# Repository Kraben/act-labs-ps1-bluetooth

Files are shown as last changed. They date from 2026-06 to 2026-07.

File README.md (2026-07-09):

# ACT Labs REX PS1 Replacement PCB

> Placa de repuesto open-source para el **ACT Labs REX Arcade Stick de PS1**.

```text
Status: Hardware V2 / KiCad actualizado
Firmware publico: PS1 Digital v1.1 OK
Firmware de apoyo: Hybrid AUTO PS1 / PS2 / BLE
BLE: operativo
Fabricacion: Gerbers pendientes de actualizar
Edicion: KiCad completo actualizado
```

## Project Dashboard

| Area | Estado | Alcance |
|---|---|---|
| Hardware | V2 / KiCad actualizado | Publico |
| Firmware PS1 | PS1 Digital v1.1 OK | Publico |
| Firmware binary | [`ActLabs_PS1_Digital_v1.1_OK.bin`](firmware/releases/PS1_Digital/v1.1/ActLabs_PS1_Digital_v1.1_OK.bin) | Publico |
| BLE HID | Operativo | Publico |
| AutoFire | Documentado | Publico |
| KiCad editable | Actualizado en `hardware/kicad/ACT_Labs_REX/` | Publico |
| Gerbers fabricacion | Pendientes de regenerar desde la revision KiCad actual | Publico |
| PS2 / DualShock | Listo en firmware Hybrid AUTO | Build de apoyo / donativos |
| PS1/PS2/BLE Hybrid | Listo en firmware Hybrid AUTO | Build de apoyo / donativos |

## Quick Links

| Recurso | Link |
|---|---|
| Sitio web | https://kraben.github.io/act-labs-ps1-bluetooth/ |
| Descargar firmware PS1 v1.1 | [`ActLabs_PS1_Digital_v1.1_OK.bin`](firmware/releases/PS1_Digital/v1.1/ActLabs_PS1_Digital_v1.1_OK.bin) |
| Firmware notes | [`docs/firmware.md`](docs/firmware.md) |
| Firmware Hybrid AUTO | [`docs/supporter-build.md`](docs/supporter-build.md) |
| Interfaz PS1 | [`docs/interfaces/ps1.md`](docs/interfaces/ps1.md) |
| Mapeo GPIO | [`docs/mapeo-gpio.md`](docs/mapeo-gpio.md) |
| Conectores | [`docs/conectores.md`](docs/conectores.md) |
| AutoFire | [`docs/autofire.md`](docs/autofire.md) |
| BOM | [`docs/bom.md`](docs/bom.md) |
| Fabricacion | [`docs/fabricacion.md`](docs/fabricacion.md) |
| KiCad editable | [`hardware/kicad/ACT_Labs_REX/`](hardware/kicad/ACT_Labs_REX/) |
| Gerbers | [`hardware/fabrication/gerbers/ACT_Labs_REX/`](hardware/fabrication/gerbers/ACT_Labs_REX/) |

## Resumen

El objetivo de este repositorio es conservar y documentar una alternativa de reemplazo para el control ACT Labs REX, ya que la pieza original ya no se fabrica ni se consigue facilmente.

El sistema usa un ESP32 DevKit V1 como controlador principal para reemplazar la electronica del ACT Labs REX Arcade Stick de PS1.

## Firmware publico PS1

La version publica actual del firmware es:

```text
ActLabs_PS1_Digital_v1.1_OK.bin
```

| Campo | Valor |
|---|---|
| Version | PS1 Digital v1.1 |
| Estado | OK |
| Target | ACT Labs REX PS1 Replacement PCB |
| Hardware | V2 / KiCad actualizado |
| Ruta | [`firmware/releases/PS1_Digital/v1.1/`](firmware/releases/PS1_Digital/v1.1/) |
| Archivo | [`ActLabs_PS1_Digital_v1.1_OK.bin`](firmware/releases/PS1_Digital/v1.1/ActLabs_PS1_Digital_v1.1_OK.bin) |
| SHA256 | `0a8994050381326bf345bf8123c105abefadabf30187247be9129a8c7f34b15c` |
| MD5 | `f61375d0dea1b9e42a6903105f5fba79` |

## Firmware Hybrid AUTO de apoyo

El firmware Hybrid AUTO es una build avanzada para ESP32 pensada como opcion de apoyo/donativos al proyecto.

| Funcion | Estado |
|---|---|
| PS1 cableado | Listo |
| PS2 / DualShock | Listo |
| Bluetooth BLE HID | Listo |
| Deteccion automatica PS1 / PS2 / BLE | Listo |

La documentacion publica se mantiene en [`docs/supporter-build.md`](docs/supporter-build.md). El codigo fuente completo del firmware Hybrid AUTO no se publica en este repositorio publico.

## Modos documentados

| Modo | Descripcion | Estado |
|---|---|---|
| PS1 cableado | ESP32 emula un control digital PS1 usando DATA, CMD, ATT, CLK y ACK. | Publico |
| Bluetooth HID | ESP32 funciona como gamepad BLE cuando se usa con bateria. | Publico |
| AutoFire | Placa secundaria con switches SPDT para activar turbo por boton. | Publico |
| Firmware Hybrid AUTO | PS1 / PS2 / BLE con deteccion automatica. | Build de apoyo / donativos |

## Estructura limpia

```text
.
├── docs/
│   ├── firmware.md
│   ├── supporter-build.md
│   ├── mapeo-gpio.md
│   ├── conectores.md
│   ├── autofire.md
│   └── interfaces/ps1.md
├── hardware/
│   ├── fabrication/
│   │   └── gerbers/
│   │       └── ACT_Labs_REX/
│   ├── kicad/
│   │   └── ACT_Labs_REX/
│   ├── pdf/
│   └── images/
├── data/
└── firmware/
    ├── ACT_Labs_Controller/
    └── releases/
        └── PS1_Digital/
            └── v1.1/
```

## Para fabricar vs para editar

| Uso | Carpeta | Contenido |
|---|---|---|
| Editar proyecto | [`hardware/kicad/ACT_Labs_REX/`](hardware/kicad/ACT_Labs_REX/) | Proyecto KiCad completo actualizado |
| Fabricar PCB | [`hardware/fabrication/gerbers/ACT_Labs_REX/`](hardware/fabrication/gerbers/ACT_Labs_REX/) | Gerbers pendientes de regenerar desde la revision KiCad actual |
| Firmware publico | [`firmware/releases/PS1_Digital/v1.1/`](firmware/releases/PS1_Digital/v1.1/) | Binario PS1 Digital v1.1 |
| Revisar PDFs | [`hardware/pdf/`](hardware/pdf/) | Esquematicos y PCB en PDF |
| Revisar datos | [`data/`](data/) | Mapeos, CSV y hojas de apoyo |

## Archivos de fabricacion actuales

> Nota: los Gerbers existentes pueden no corresponder todavia a la revision KiCad mas reciente. Regenerar y validar antes de fabricar.

| Archivo | Proposito |
|---|---|
| `ACT_Labs_REX-F_Cu.gbr` | Cobre superior |
| `ACT_Labs_REX-B_Cu.gbr` | Cobre inferior |
| `ACT_Labs_REX-F_Mask.gbr` | Mascara superior |
| `ACT_Labs_REX-B_Mask.gbr` | Mascara inferior |
| `ACT_Labs_REX-F_Silkscreen.gbr` | Serigrafia superior |
| `ACT_Labs_REX-B_Silkscreen.gbr` | Serigrafia inferior |
| `ACT_Labs_REX-Edge_Cuts.gbr` | Contorno de PCB |
| `ACT_Labs_REX-PTH.drl` | Taladros metalizados |
| `ACT_Labs_REX-NPTH.drl` | Taladros no metalizados |
| `ACT_Labs_REX-job.gbrjob` | Job file de fabricacion |

## Referencias de hardware

| Archivo | Descripcion |
|---|---|
| [`hardware/pdf/ACT_Labs_REX.pdf`](hardware/pdf/ACT_Labs_REX.pdf) | Esquematico principal |
| [`hardware/pdf/ArcLabsPCB.pdf`](hardware/pdf/ArcLabsPCB.pdf) | PCB principal |
| [`hardware/pdf/AutoFire.pdf`](hardware/pdf/AutoFire.pdf) | Esquematico AutoFire |
| [`hardware/pdf/AutoFirePCB.pdf`](hardware/pdf/AutoFirePCB.pdf) | PCB AutoFire |
| [`hardware/fabrication/`](hardware/fabrication/) | BOM/POS de fabricacion |

## Pines principales V2

| Signal | GPIO |
|---|---:|
| DATA | 19 |
| CMD | 23 |
| ATT | 5 |
| CLK | 18 |
| ACK | 4 |
| START | 2 |
| SELECT | 16 |
| AF_MODE | 15 |

## Apoyo / donativos

GitHub Pages puede funcionar como landing page del proyecto y enlazar a una plataforma externa para apoyo/donativos.

Opciones recomendadas:

| Opcion | Uso recomendado |
|---|---|
| GitHub Pages + PayPal/Mercado Pago | Catalogo simple y contacto directo |
| GitHub Pages + Gumroad/Payhip/Ko-fi | Entrega de builds de apoyo, firmware o archivos digitales |
| GitHub Pages + Stripe Payment Links | Botones de pago profesionales sin backend propio |
| GitHub Sponsors | Apoyo/donaciones recurrentes |

El repositorio publico mantiene hardware, documentacion y firmware PS1 disponible. La build Hybrid AUTO se maneja como opcion avanzada de apoyo para sostener el desarrollo.

## Proximos pasos

- [ ] Regenerar Gerbers desde la revision KiCad actual.
- [ ] Validar Gerbers nuevos contra visualizador antes de mandar a fabricar.
- [ ] Validar continuidad START/SELECT contra GND en PCB actualizada.
- [ ] Validar continuidad entre PCB principal, placa AutoFire y conectores JP.
- [ ] Revisar la ruta de alimentacion `BATT_FROM_TP`, TP4056, LD1117-3.3 y diodos SS14.
- [ ] Validar el firmware PS1 actualizado contra hardware fisico.
- [ ] Confirmar pull-ups reales contra la PCB antes de fabricar.
- [ ] Preparar binario, checksums y guia de flasheo para la build Hybrid AUTO de apoyo.

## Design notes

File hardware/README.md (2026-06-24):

# Hardware

Esta carpeta contiene referencias de hardware, PDFs, imágenes, exportaciones de fabricación e inventario de fuentes KiCad del proyecto ACT Labs PS1 Bluetooth / AutoFire.

## PDFs

- `pdf/ACT_Labs_REX.pdf`: esquemático principal de conversión de tablero PS1.
- `pdf/ArcLabsPCB.pdf`: vista de PCB principal.
- `pdf/AutoFire.pdf`: esquemático de la placa AutoFire.
- `pdf/AutoFirePCB.pdf`: vista de PCB AutoFire.

## Imágenes

- `images/Led-Switch.png`: detalle de LED / switch de encendido.
- `images/Partcial_SCHM.png`: captura parcial del esquemático principal.
- `images/SW_part.png`: captura de la placa de switches AutoFire.

## Fabricación

Archivos de resumen derivados de las exportaciones KiCad recibidas:

- `fabrication/ACT_Labs_REX_BOM_summary.csv`: BOM resumido de placa principal.
- `fabrication/ACT_Labs_REX_POS_summary.csv`: posiciones resumidas de placa principal.
- `fabrication/autofire_bom_summary.txt`: BOM resumido de placa AutoFire.
- `fabrication/autofire_pos_summary.txt`: posiciones resumidas de placa AutoFire.

Resumen de exportaciones recibidas:

| Placa | BOM | POS | Componentes |
|---|---:|---:|---:|
| ACT_Labs_REX | 35 líneas | 40 líneas | 27 top / 13 bottom |
| AutoFire | 13 líneas | 13 líneas | 13 top |

## Fuentes KiCad

El inventario de fuentes KiCad recibidas y sus hashes está en `kicad/SOURCES.md`.

## Validaciones recomendadas

- Verificar continuidad de GND entre placas.
- Confirmar orientación de D1/D3 Schottky.
- Confirmar que `BATT_FROM_TP` entra a la ruta de alimentación correcta y no directamente a `3V3`.
- Confirmar pull-ups de DATA/ACK a 4.7 kΩ según BOM V2.
- Antes de fabricar, regenerar BOM/POS desde la misma revisión de KiCad que se use para Gerbers.

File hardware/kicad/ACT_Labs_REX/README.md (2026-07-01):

# ACT Labs REX KiCad Sources

Fuentes editables de KiCad para **ACT Labs REX PCB V2.2**.

## Uso

Esta carpeta es para editar el proyecto en KiCad.

Para fabricar usar los Gerbers exportados en:

```text
hardware/fabrication/gerbers/ACT_Labs_REX/
```

## Archivos principales

| Archivo | Proposito |
|---|---|
| ACT_Labs_REX.kicad_pro | Proyecto KiCad |
| ACT_Labs_REX.kicad_sch | Esquematico principal |
| ACT_Labs_REX.kicad_pcb | PCB principal |
| Placa_2.kicad_sch | Esquematico de placa secundaria / AutoFire |

## Reglas

- Mantener aqui solo fuentes editables de KiCad.
- No mezclar Gerbers ni salidas de fabricacion en esta carpeta.
- No subir backups, autosaves ni archivos temporales.
- Exportar salidas de fabricacion hacia `hardware/fabrication/gerbers/ACT_Labs_REX/`.

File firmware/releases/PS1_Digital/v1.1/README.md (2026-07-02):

# ACT Labs PS1 Digital Firmware v1.1

Firmware publico para la placa **ACT Labs REX PS1 Replacement PCB**.

## Archivo

```text
ActLabs_PS1_Digital_v1.1_OK.bin
```

## Estado

| Campo | Valor |
|---|---|
| Version | PS1 Digital v1.1 |
| Estado | OK |
| Target | ACT Labs REX PS1 Replacement PCB |
| Hardware | V2 / PCB V2.2 |

## Checksum

```text
SHA256: 0a8994050381326bf345bf8123c105abefadabf30187247be9129a8c7f34b15c
MD5: f61375d0dea1b9e42a6903105f5fba79
```

## Politica de publicacion

Este release contiene el firmware publico PS1 Digital.

El protocolo PS2 / DualShock y el firmware hibrido PS1/PS2/BLE permanecen reservados para distribucion privada/paywall.

## Antes de flashear

- Confirmar que el hardware sea ACT Labs REX V2 / PCB V2.2.
- Confirmar checksum del archivo descargado.
- Validar alimentacion y cableado antes de probar en consola.

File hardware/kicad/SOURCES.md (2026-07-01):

# Fuentes KiCad V2

Inventario de archivos recibidos para trazabilidad de la revision V2 / PCB V2.2.

## Estructura actual

```text
hardware/kicad/
├── ACT_Labs_REX/
│   ├── ACT_Labs_REX.kicad_pro
│   ├── ACT_Labs_REX.kicad_sch
│   ├── ACT_Labs_REX.kicad_pcb
│   └── Placa_2.kicad_sch
└── SOURCES.md
```

## Fabricacion

Los Gerbers actuales estan separados de las fuentes editables:

```text
hardware/fabrication/gerbers/ACT_Labs_REX/
├── ACT_Labs_REX-F_Cu.gbr
├── ACT_Labs_REX-B_Cu.gbr
├── ACT_Labs_REX-F_Mask.gbr
├── ACT_Labs_REX-B_Mask.gbr
├── ACT_Labs_REX-F_Paste.gbr
├── ACT_Labs_REX-B_Paste.gbr
├── ACT_Labs_REX-F_Silkscreen.gbr
├── ACT_Labs_REX-B_Silkscreen.gbr
├── ACT_Labs_REX-Edge_Cuts.gbr
├── ACT_Labs_REX-PTH.drl
├── ACT_Labs_REX-NPTH.drl
└── ACT_Labs_REX-job.gbrjob
```

## Regla de limpieza

- Para editar: usar `hardware/kicad/ACT_Labs_REX/`.
- Para fabricar: usar `hardware/fabrication/gerbers/ACT_Labs_REX/`.
- No mezclar archivos Gerber dentro de KiCad.
- No mezclar fuentes KiCad dentro de fabricacion.
- No subir backups, autosaves o temporales de KiCad.

## Nota

Los CSV de resumen de BOM/POS de esta revision permanecen en `hardware/fabrication/`.

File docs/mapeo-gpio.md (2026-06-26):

# Mapeo GPIO ESP32 Rev 1.4 / V2

Mapa funcional actualizado desde `ACT_Labs_Mapeo_Consolidado(2).xlsx` y `gpio_mapping.csv`.

Referencia externa usada como apoyo: Random Nerd Tutorials, `ESP32 Pinout Reference: Which GPIO pins should you use?`, agregada para validar restricciones generales de GPIO del ESP32.

## Botones frontales

| # | Señal / función | GPIO ESP32 | JP / conector | Pin conector | Tipo | Pull-up | Notas |
|---:|---|---|---|---|---|---|---|
| 1 | Triángulo | GPIO14 | JP1 / JP2 | 6 / 1 | INPUT | PULLUP interno | AF_TRIANGULO - SW7 Placa_2 |
| 2 | Círculo | GPIO26 | JP1 / JP2 | 7 / 2 | INPUT | PULLUP interno | AF_CIRCULO - SW3 Placa_2 |
| 3 | Cuadrado | GPIO12 | JP1 / JP2 | 4 / 6 | INPUT | PULLUP interno | AF_CUADRADO - SW6 Placa_2 |
| 4 | Cruz | GPIO25 | JP1 / JP2 | 8 / 4 | INPUT | PULLUP interno | AF_CRUZ - SW2 Placa_2 |

## Botones laterales

| # | Señal / función | GPIO ESP32 | JP / conector | Pin conector | Tipo | Pull-up | Notas |
|---:|---|---|---|---|---|---|---|
| 6 | L1 | GPIO27 | JP1 / JP4 | 7 / 5 | INPUT | PULLUP interno | AF_L1 - SW1 Placa_2 |
| 7 | L2 | GPIO32 | JP1 / JP4 | 10 / 4 | INPUT | PULLUP interno | AF_L2 - SW4 Placa_2 |
| 8 | R1 | GPIO33 | JP1 / JP4 | 8 / 1 | INPUT | PULLUP interno | AF_R1 - SW5 Placa_2 |
| 9 | R2 | GPIO13 | JP1 / JP4 | 3 / 7 | INPUT | PULLUP interno | AF_R2 - SW8 Placa_2 |

## D-Pad

| # | Señal / función | GPIO ESP32 | JP | Pin | Tipo | Pull-up | Notas |
|---:|---|---|---|---|---|---|---|
| 11 | Arriba | GPIO36 | JP3 | 8 | INPUT ONLY | 10k externo R1 | Sin pull-up interno |
| 12 | Abajo | GPIO34 | JP3 | 2 | INPUT ONLY | 10k externo R4 | Sin pull-up interno |
| 13 | Izquierda | GPIO35 | JP3 | 4 | INPUT ONLY | 10k externo R3 | Sin pull-up interno |
| 14 | Derecha | GPIO39 | JP3 | 6 | INPUT ONLY | 10k externo R5 | Sin pull-up interno |

## START / SELECT

| # | Señal | GPIO ESP32 | Conector | Pin conector | Tipo | Pull-up | Notas |
|---:|---|---|---|---|---|---|---|
| 16 | START | GPIO2 | JP1 / START1 | 12 / - | INPUT | PULLUP interno + R6 15k | SW_Push_Dual; GPIO2 es pin de arranque y puede afectar boot si se fuerza en nivel incorrecto |
| 17 | SELECT | GPIO16 | JP1 / SELECT1 | 12 / - | INPUT | PULLUP interno + R7 15k | SW_Push_Dual |

## Interfaz PS1 SPI

| # | Señal | GPIO ESP32 | Conector | Pin | Tipo | Pull-up | Notas |
|---:|---|---|---|---|---|---|---|
| 19 | PS1_DATA / MISO | GPIO19 | PS1_Conn | 1 | OUTPUT | R1 1k a 3V3 | Mando a consola; coincide con MISO VSPI por defecto |
| 20 | PS1_CMD / MOSI | GPIO23 | PS1_Conn | 2 | INPUT | - | Consola a mando; coincide con MOSI VSPI por defecto |
| 21 | PS1_ATT / CS | GPIO5 | PS1_Conn | 6 | INPUT | - | LOW = consola iniciando comunicación; GPIO5 es strapping pin |
| 22 | PS1_CLK | GPIO18 | PS1_Conn | 7 | INPUT | - | Reloj aprox 250kHz; coincide con CLK VSPI por defecto |
| 23 | PS1_ACK | GPIO4 | PS1_Conn | 8 | OUTPUT | - | Pulso LOW aprox 2us |

## AutoFire / alimentación

| # | Señal | GPIO ESP32 | JP | Pin | Tipo | Pull-up | Notas |
|---:|---|---|---|---|---|---|---|
| 25 | AF_MODE | GPIO15 | JP1 | 2 | INPUT | PULLUP interno | SW9 Placa_2; GPIO15 es strapping pin y puede emitir señal durante boot |
| 26 | BATT_FROM_TP | VIN | JP1 | 12 | PWR | - | SW10 Placa_2 - Encendido modo BT |
| 27 | VCC_3V3 | 3V3 | JP1 | 1 | PWR | - | Alimenta Placa_2 |
| 28 | GND | GND | JP1 | 13 | GND | - | Referencia común |

## Constantes sugeridas para firmware

```cpp
static constexpr uint8_t PIN_PS1_DATA = 19;
static constexpr uint8_t PIN_PS1_CMD  = 23;
static constexpr uint8_t PIN_PS1_ATT  = 5;
static constexpr uint8_t PIN_PS1_CLK  = 18;
static constexpr uint8_t PIN_PS1_ACK  = 4;

static constexpr uint8_t PIN_START   = 2;
static constexpr uint8_t PIN_SELECT  = 16;
static constexpr uint8_t PIN_AF_MODE = 15;
```

## Notas ESP32 pinout

- GPIO34, GPIO35, GPIO36 y GPIO39 son solo entrada y no tienen pull-up/pull-down internos; por eso el D-Pad necesita resistencias externas.
- GPIO6 a GPIO11 no deben usarse porque normalmente estan conectados a la memoria SPI flash interna del ESP32.
- GPIO2, GPIO5, GPIO12 y GPIO15 son pines sensibles durante el arranque; evitar que botones o switches los fuercen a niveles no deseados al encender.
- El mapeo PS1 usa GPIO23, GPIO19, GPIO18 y GPIO5, que coinciden con la asignacion VSPI habitual del ESP32: MOSI=23, MISO=19, CLK=18 y CS=5.

## Referencias

- Random Nerd Tutorials - ESP32 Pinout Reference: https://randomnerdtutorials.com/esp32-pinout-reference-gpios/

## Nota de revisión

El mapeo consolidado Rev 1.4 corrige `START` a GPIO2 y `SELECT` a GPIO16. Esto reemplaza la tabla anterior que los listaba como GPIO21/GPIO22.

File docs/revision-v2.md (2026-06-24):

# Revision V2 / PCB V2.2

## Estado recibido

- Proyecto principal: `ACT_Labs_REX`
- Titulo PCB principal: `CONVERSION PLACA ARCADE PS1-BLUETOOTH`
- Revision PCB principal: `2.2`
- KiCad: 10.0
- BLE: operativo
- PS1: en depuracion de `ACK` / `DATA`

## Cambios incorporados a documentacion

| Area | Ajuste |
|---|---|
| Arquitectura | Se documenta ESP32 DevKit V1, TP4056 externo, bateria PS Vita 3.7 V, LD1117-3.3 y Schottky |
| BOM | Se actualiza desde CSV KiCad V2 |
| Conectores | Se agrega TP4056, bateria PS Vita, J1-J6, JP1 y AutoFire |
| Firmware | Se documentan pines Rev 1.4 / V2 y resumen de protocolo PS1 |
| Mapeo GPIO | Se sincroniza con ACT_Labs_Mapeo_Consolidado(2).xlsx y gpio_mapping.csv |
| Fabricacion | Se agregan BOM/POS de placa principal y AutoFire |

## Valores importantes Rev 1.4 / V2

| Senal / componente | Valor / GPIO |
|---|---|
| DATA | GPIO19 |
| CMD | GPIO23 |
| ATT | GPIO5 |
| CLK | GPIO18 |
| ACK | GPIO4 |
| START | GPIO2 |
| SELECT | GPIO16 |
| AF_MODE | GPIO15 |
| Regulador | LD1117S33TR_SOT223 |
| Schottky | SS14 / 1N5817 |

## Archivos revisados en esta actualizacion

| Archivo | Uso |
|---|---|
| `ACT_Labs_Mapeo_Consolidado(2).xlsx` | Mapeo consolidado Rev 1.4 |
| `gpio_mapping.csv` | Fuente tabular del mapeo GPIO |
| `jp1_conector_puente.csv` | Fuente de verdad para pines JP1 |
| `placa_2_autofire.csv` | Tabla funcional de switches AutoFire |
| `firmware_resumen.md` | Resumen de modo, turbo y protocolo PS1 |
| `ACT_Labs_REX_BOM(1).csv` | BOM placa principal |
| `ACT_Labs_REX_POS(1).csv` | POS placa principal |
| `AutoFire_BOM(1).csv` | BOM AutoFire |
| `AutoFire_POS(1).csv` | POS AutoFire |

## Correcciones aplicadas

1. `START` queda en GPIO2.
2. `SELECT` queda en GPIO16.
3. El README y la documentacion de firmware fueron corregidos para reemplazar GPIO21/GPIO22.
4. La tabla de conectores usa `jp1_conector_puente.csv` como fuente de verdad para JP1.
5. Se documenta una inconsistencia detectada en `placa_2_autofire.csv`: algunos pines JP1 no coinciden con la tabla JP1. En conectores se normaliza usando JP1.

## Pendientes tecnicos

1. Subir fuentes KiCad completas si se requiere tener el proyecto 100% editable dentro del repositorio.
2. Generar Gerbers oficiales desde KiCad 10.
3. Validar footprints de switches SPDT antes de fabricar.
4. Medir timing PS1 con analizador logico.
5. Confirmar si el termistor de bateria PS Vita se deja aislado o se integra a una proteccion futura.

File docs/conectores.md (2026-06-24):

# Conectores V2

## TP4056

| Punto | Conexion |
|---|---|
| OUT+ | BATT_FROM_TP |
| OUT- | GND |
| BATT+ | Positivo de bateria PS Vita |
| BATT- | Negativo de bateria PS Vita |

## Bateria PS Vita

| Cable | Senal | Nota |
|---|---|---|
| Rojo | BAT+ | Positivo bateria |
| Negro | BAT- | Negativo bateria |
| Blanco | Termistor | Sin uso en esta revision |

## Conector PS1 J1

| Pin | Senal |
|---:|---|
| 1 | DATA |
| 2 | CMD |
| 3 | VIB_NC |
| 4 | GND |
| 5 | VCC_3V3 |
| 6 | ATT |
| 7 | CLK |
| 8 | NC |
| 9 | ACK |

## JP1 - Conector puente de 13 pines

| Pin JP1 | Senal | Desde | Hacia | GPIO ESP32 | Descripcion |
|---:|---|---|---|---|---|
| 1 | VCC_3V3 | Placa Principal | Placa_2 | 3V3 | Alimentacion 3.3V hacia Placa_2 |
| 2 | AF_MODE | Placa_2 SW9 | ESP32 | GPIO15 | Modo turbo global |
| 3 | AF_R2 | Placa_2 SW8 | ESP32 | GPIO13 | Turbo R2 |
| 4 | AF_CUADRADO | Placa_2 SW6 | ESP32 | GPIO12 | Turbo Cuadrado |
| 5 | NC | - | - | NC | No conectado |
| 6 | AF_TRIANGULO | Placa_2 SW7 | ESP32 | GPIO14 | Turbo Triangulo |
| 7 | AF_L1 | Placa_2 SW1 | ESP32 | GPIO27 | Turbo L1 |
| 8 | AF_R1 | Placa_2 SW5 | ESP32 | GPIO33 | Turbo R1 |
| 9 | AF_CRUZ | Placa_2 SW2 | ESP32 | GPIO25 | Turbo Cruz |
| 10 | AF_CIRCULO | Placa_2 SW3 | ESP32 | GPIO26 | Turbo Circulo |
| 11 | AF_L2 | Placa_2 SW4 | ESP32 | GPIO32 | Turbo L2 |
| 12 | BATT_FROM_TP | Placa_2 SW10 | ESP32 VIN + D1 | VIN | Encendido modo BT - pasa por D1 SS14 |
| 13 | GND | Placa Principal | Placa_2 | GND | Referencia comun |

## Conectores internos de placa principal

| Ref | Nombre | Pines | Funcion |
|---|---|---:|---|
| J2 | JP1 Autofire | 13 | Puente hacia placa AutoFire / senales de turbo |
| J3 | JP3 Palanca Direccional | 8 | D-Pad / palanca direccional |
| J4 | JP4 Botones Frontales | 8 | Triangulo, circulo, cruz, cuadrado y GND |
| J5 | JP5 Botones laterales | 8 | L1, L2, R1, R2 y GND |
| J6 | JP6 Autofire | 13 | Segundo conector de AutoFire segun PCB V2 |

## Placa AutoFire

| SW | Senal AF | Boton | JP1 Pin | GPIO | Funcion | Notas |
|---|---|---|---:|---|---|---|
| SW1 | AF_L1 | L1 | 7 | GPIO27 | Turbo L1 | OFF=boton directo, ON=GND->Turbo |
| SW2 | AF_CRUZ | Cruz | 9 | GPIO25 | Turbo Cruz | OFF=boton directo, ON=GND->Turbo |
| SW3 | AF_CIRCULO | Circulo | 10 | GPIO26 | Turbo Circulo | OFF=boton directo, ON=GND->Turbo |
| SW4 | AF_L2 | L2 | 11 | GPIO32 | Turbo L2 | OFF=boton directo, ON=GND->Turbo |
| SW5 | AF_R1 | R1 | 8 | GPIO33 | Turbo R1 | OFF=boton directo, ON=GND->Turbo |
| SW6 | AF_CUADRADO | Cuadrado | 4 | GPIO12 | Turbo Cuadrado | OFF=boton directo, ON=GND->Turbo |
| SW7 | AF_TRIANGULO | Triangulo | 6 | GPIO14 | Turbo Triangulo | OFF=boton directo, ON=GND->Turbo |
| SW8 | AF_R2 | R2 | 3 | GPIO13 | Turbo R2 | OFF=boton directo, ON=GND->Turbo |
| SW9 | AF_MODE | MODE | 2 | GPIO15 | Modo AF global | Reservado para uso futuro |
| SW10 | BATT_FROM_TP | - | 12 | VIN | Encendido BT | ON=alimenta ESP32 desde bateria |

## Nota de revision

El archivo `placa_2_autofire.csv` recibido lista algunos pines JP1 de forma inconsistente con `jp1_conector_puente.csv`. Para la documentacion de conectores se usa JP1 como fuente de verdad electrica: AF_CRUZ=pin 9, AF_CIRCULO=pin 10 y AF_L2=pin 11.

## Validaciones antes de energizar

1. Confirmar continuidad de GND entre TP4056, placa principal y AutoFire.
2. Confirmar que OUT+ del TP4056 llegue a BATT_FROM_TP y no directamente a VCC_3V3.
3. Confirmar que el cable blanco de la bateria PS Vita quede aislado si no se usa termistor.
4. Verificar orientacion de diodos Schottky D1/D3 antes de conectar bateria.

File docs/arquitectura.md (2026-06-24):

# Arquitectura V2

## Descripción general

El proyecto convierte un tablero ACT-LABS / PS1 en un control híbrido con dos modos de operación:

- **BLE HID**: gamepad Bluetooth usando ESP32.
- **PS1 cableado**: emulación de control digital PS1 usando las líneas `DATA`, `CMD`, `ATT`, `CLK` y `ACK`.

## Bloques principales

| Bloque | Función |
|---|---|
| ESP32 DevKit V1 | Lectura de botones, lógica AutoFire, BLE HID y emulación PS1 |
| TP4056 externo | Carga/protección de batería 3.7 V |
| Batería PS Vita 3.7 V | Alimentación portátil para modo Bluetooth |
| LD1117-3.3 | Regulación a 3.3 V para lógica |
| Diodo Schottky D1 | Protección/aislamiento de alimentación |
| Placa AutoFire | Switches SPDT para turbo por botón y encendido |
| Conector PS1 | Interfaz cableada con consola PS1/PS2 |

## Alimentación

La alimentación V2 queda documentada así:

1. La batería PS Vita entra al módulo TP4056.
2. `OUT+` del TP4056 se conecta a `BATT_FROM_TP`.
3. `OUT-` del TP4056 va a `GND`.
4. `BATT_FROM_TP` se conmuta desde `SW10` para alimentar el modo Bluetooth.
5. La placa incluye LD1117-3.3 para obtener `VCC_3V3`.
6. D1 usa diodo Schottky, con opción SS14 / 1N5817 según disponibilidad.

## Interfaz PS1

| Señal | GPIO ESP32 | Rol |
|---|---:|---|
| DATA | 19 | Mando -> consola |
| CMD | 23 | Consola -> mando |
| ATT | 5 | Selección / atención de consola |
| CLK | 18 | Reloj de consola |
| ACK | 4 | Pulso de acknowledge del mando |

El protocolo PS1 sigue en depuración, específicamente en la temporización de `ACK` y la estabilidad de `DATA`.

## Estado

| Área | Estado |
|---|---|
| Hardware | V2 / PCB V2.2 |
| BLE | Operativo |
| PS1 | En depuración de protocolo |
| KiCad | Archivos fuente y exportaciones BOM/POS recibidos |

## Notas de validación

- Confirmar pull-ups de `DATA` y `ACK` con R6/R7 de 4.7 kΩ.
- Verificar continuidad de GND entre placa principal, AutoFire y TP4056.
- Validar orientación de los diodos Schottky D1/D3.
- Confirmar que `BATT_FROM_TP` no alimente directamente `3V3`.

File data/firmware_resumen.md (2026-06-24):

# Resumen Firmware

## Detección de modo

| Condición | Modo | Descripción |
|---|---|---|
| PS1_ATT = LOW al arrancar | Modo PS1 | Consola PS1/PS2 activa — emulación SPI |
| PS1_ATT = HIGH al arrancar | Modo Bluetooth | Sin consola — HID Gamepad BLE |
| SW10 Placa_2 = OFF | Apagado | Sin alimentación desde batería |

## Lógica Turbo

| Condición GPIO | Duración | Comportamiento |
|---|---:|---|
| GPIO HIGH | — | Botón suelto — sin acción |
| GPIO LOW | < 150 ms | Pulsación normal del usuario |
| GPIO LOW continuo | > 150 ms | SW ON jalando a GND = TURBO activo |
| TURBO activo | 50 ms ON / 50 ms OFF | 10 pulsaciones por segundo |

## Protocolo PS1 SPI

| Byte | Valor | Descripción |
|---:|---|---|
| 0 | 0xFF | Idle |
| 1 | 0x41 | Tipo: Digital Controller |
| 2 | 0x5A | Fijo siempre |
| 3 | Botones 1 | Select/Start/D-Pad — 0=presionado |
| 4 | Botones 2 | L2/R2/L1/R1/△/○/×/□ — 0=presionado |

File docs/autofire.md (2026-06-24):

# AutoFire

## Concepto

Cada botón con AutoFire se conecta a un switch SPDT. El switch permite usar el botón en modo directo o forzar una condición de activación de turbo llevando la señal a GND.

## Mapeo de switches

| SW | Señal AF | Botón | JP1 Pin | GPIO ESP32 | Función | Notas |
|---|---|---|---:|---|---|---|
| SW1 | AF_L1 | L1 | 7 | GPIO27 | Turbo L1 | OFF=directo, ON=GND→Turbo |
| SW2 | AF_CRUZ | × Cruz | 8 | GPIO25 | Turbo × | OFF=directo, ON=GND→Turbo |
| SW3 | AF_CIRCULO | ○ Círculo | 7 | GPIO26 | Turbo ○ | OFF=directo, ON=GND→Turbo |
| SW4 | AF_L2 | L2 | 10 | GPIO32 | Turbo L2 | OFF=directo, ON=GND→Turbo |
| SW5 | AF_R1 | R1 | 8 | GPIO33 | Turbo R1 | OFF=directo, ON=GND→Turbo |
| SW6 | AF_CUADRADO | □ Cuadrado | 4 | GPIO12 | Turbo □ | OFF=directo, ON=GND→Turbo |
| SW7 | AF_TRIANGULO | △ Triángulo | 6 | GPIO14 | Turbo △ | OFF=directo, ON=GND→Turbo |
| SW8 | AF_R2 | R2 | 3 | GPIO13 | Turbo R2 | OFF=directo, ON=GND→Turbo |
| SW9 | AF_MODE | MODE | 2 | GPIO15 | Modo AF global | Reservado para uso futuro |
| SW10 | BATT_FROM_TP | — | 12 | VIN | Encendido BT | ON=alimenta ESP32 desde batería |

## Lógica sugerida

| Condición GPIO | Duración | Comportamiento |
|---|---:|---|
| HIGH | — | Botón suelto |
| LOW | < 150 ms | Pulsación normal |
| LOW continuo | > 150 ms | Turbo activo |
| Turbo activo | 50 ms ON / 50 ms OFF | 10 pulsaciones por segundo |

## Consideraciones

- Confirmar que todos los botones estén en lógica activa LOW.
- Aplicar debounce por software.
- Separar la lectura física del botón y el estado virtual enviado al protocolo PS1/BLE.
- Guardar un flag por botón: `physical_pressed`, `turbo_enabled`, `virtual_pressed`.

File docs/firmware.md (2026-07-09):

# Firmware

## Version publica actual

| Campo | Valor |
|---|---|
| Version | PS1 Digital v1.1 |
| Estado | OK |
| Archivo | [`ActLabs_PS1_Digital_v1.1_OK.bin`](../firmware/releases/PS1_Digital/v1.1/ActLabs_PS1_Digital_v1.1_OK.bin) |
| Ruta | [`firmware/releases/PS1_Digital/v1.1/`](../firmware/releases/PS1_Digital/v1.1/) |
| Target | ACT Labs REX PS1 Replacement PCB |
| Hardware | V2 / KiCad actualizado |
| SHA256 | `0a8994050381326bf345bf8123c105abefadabf30187247be9129a8c7f34b15c` |
| MD5 | `f61375d0dea1b9e42a6903105f5fba79` |

## Modos

- PS1: firmware publico actualizado a PS1 Digital v1.1 OK para el alcance ACT Labs REX / PS1.
- BLE HID: funcional.
- PS2 / DualShock: listo en firmware Hybrid AUTO para build de apoyo/donativos.
- Hibrido PS1/PS2/BLE: listo en firmware Hybrid AUTO para build de apoyo/donativos.

## Politica de publicacion

Este repositorio publico conserva la documentacion, hardware, Gerbers y firmware PS1 disponible para la placa de repuesto ACT Labs REX.

El firmware Hybrid AUTO se maneja como **build de apoyo/donativos** para sostener el desarrollo. Esta build agrega PS1, PS2 / DualShock, Bluetooth BLE HID y deteccion automatica de modo.

No se publica aqui el codigo fuente completo del firmware Hybrid AUTO. La documentacion publica describe el alcance, compatibilidad esperada, checklist de pruebas y recomendaciones de flasheo.

## Firmware Hybrid AUTO de apoyo

| Campo | Valor |
|---|---|
| Nombre | Hybrid AUTO |
| Plataforma | ESP32 DevKit V1 |
| Modos | PS1 / PS2 / BLE |
| Deteccion | Automatica |
| Distribucion | Build de apoyo / donativos |
| Fuente completa | No publicada en este repositorio publico |
| Documentacion | [`supporter-build.md`](supporter-build.md) |

## Deteccion de modo publico

| Condicion | Modo | Descripcion |
|---|---|---|
| Consola PS1 activa | Modo PS1 | Emulacion digital PS1 |
| Consola PS2 activa | Modo PS2 | Emulacion PS2 / DualShock en build Hybrid AUTO |
| Sin actividad de consola | Modo Bluetooth | HID Gamepad BLE |
| SW10 Placa_2 = OFF | Apagado | Sin alimentacion desde bateria |

## Pines Rev 1.4 / V2

```cpp
static constexpr uint8_t PIN_PS1_DATA = 19;
static constexpr uint8_t PIN_PS1_CMD  = 23;
static constexpr uint8_t PIN_PS1_ATT  = 5;
static constexpr uint8_t PIN_PS1_CLK  = 18;
static constexpr uint8_t PIN_PS1_ACK  = 4;

static constexpr uint8_t PIN_START   = 2;
static constexpr uint8_t PIN_SELECT  = 16;
static constexpr uint8_t PIN_AF_MODE = 15;
```

## Logica Turbo / AutoFire

| Condicion GPIO | Duracion | Comportamiento |
|---|---:|---|
| GPIO HIGH | - | Boton suelto - sin accion |
| GPIO LOW | < 150 ms | Pulsacion normal del usuario |
| GPIO LOW continuo | > 150 ms | SW ON jalando a GND = TURBO activo |
| TURBO activo | 50 ms ON / 50 ms OFF | 10 pulsaciones por segundo |

## Protocolo PS1 SPI

| Byte | Valor | Descripcion |
|---:|---|---|
| 0 | 0xFF | Idle |
| 1 | 0x41 | Tipo: Digital Controller |
| 2 | 0x5A | Fijo siempre |
| 3 | Botones 1 | Select/Start/D-Pad - 0=presionado |
| 4 | Botones 2 | L2/R2/L1/R1/Triangulo/Circulo/Cruz/Cuadrado - 0=presionado |

## Protocolo PS2

El protocolo PS2 / DualShock ya fue desarrollado para la build Hybrid AUTO de apoyo/donativos.

Estado publico:

- No se publica el codigo completo en este repositorio.
- No se documentan aqui los detalles completos de handshake ni modo analogico.
- Se mantiene como referencia de roadmap y compatibilidad de la build de apoyo.

## Estado actual

| Subsistema | Estado |
|---|---|
| Firmware PS1 | PS1 Digital v1.1 OK publicado como binario |
| BLE HID | Operativo |
| PS2 / DualShock | Listo en build Hybrid AUTO de apoyo |
| Hibrido PS1/PS2/BLE | Listo en build Hybrid AUTO de apoyo |
| AutoFire | Pendiente de validar con placa fisica |

## Notas para depuracion PS1

1. Usar analizador logico con canales ATT, CLK, CMD, DATA y ACK.
2. Confirmar que DATA quede estable antes del flanco esperado de CLK.
3. Confirmar pulso ACK en LOW y retorno a HIGH.
4. Probar primero respuesta digital basica 0x41 0x5A antes de mapear botones completos.
5. Validar START en GPIO2 y SELECT en GPIO16.

## Notas de release

- Descargar el binario publico PS1 desde `firmware/releases/PS1_Digital/v1.1/`.
- Confirmar checksum antes de flashear.
- Probar primero en hardware ACT Labs REX V2 / KiCad actualizado.
- Para la build Hybrid AUTO de apoyo, publicar binario, checksums y guia de flasheo por separado.

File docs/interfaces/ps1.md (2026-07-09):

# Interfaz PS1

## Estado

- Firmware PS1 publico: actualizado para el alcance ACT Labs REX / PS1.
- Objetivo publico: emular un control digital PS1 cableado desde ESP32.
- Protocolo PS2 / DualShock: listo en la build Hybrid AUTO de apoyo/donativos.
- Firmware hibrido PS1/PS2/BLE: listo en la build Hybrid AUTO, no publicado como codigo fuente completo en este repositorio publico.

## Pines Rev 1.4 / V2

| Senal | GPIO ESP32 | Direccion | Descripcion |
|---|---:|---|---|
| PS1_DATA | GPIO19 | Salida | Mando hacia consola |
| PS1_CMD | GPIO23 | Entrada | Consola hacia mando |
| PS1_ATT | GPIO5 | Entrada | Seleccion / atencion de consola |
| PS1_CLK | GPIO18 | Entrada | Reloj de consola |
| PS1_ACK | GPIO4 | Salida | Pulso de acknowledge |

## Conector PS1

| Pin | Senal |
|---:|---|
| 1 | DATA |
| 2 | CMD |
| 3 | VIB_NC |
| 4 | GND |
| 5 | VCC_3V3 |
| 6 | ATT |
| 7 | CLK |
| 8 | NC |
| 9 | ACK |

## Deteccion de modo publico

| Condicion | Modo |
|---|---|
| PS1_ATT = LOW al arrancar | Modo PS1 |
| PS1_ATT = HIGH al arrancar | Modo Bluetooth |

## Protocolo digital base PS1

| Byte | Valor | Descripcion |
|---:|---|---|
| 0 | 0xFF | Idle |
| 1 | 0x41 | Tipo: Digital Controller |
| 2 | 0x5A | Byte fijo |
| 3 | Botones 1 | Select / Start / D-Pad, 0 = presionado |
| 4 | Botones 2 | L2 / R2 / L1 / R1 / Triangulo / Circulo / Cruz / Cuadrado, 0 = presionado |

## Nota sobre PS2

PS1 y PS2 comparten conector y una base de comunicacion similar, pero el soporte PS2 / DualShock completo no forma parte del firmware PS1 publico.

Estado:

- Protocolo PS2 / DualShock: listo en build Hybrid AUTO.
- Firmware hibrido PS1/PS2/BLE: listo en build Hybrid AUTO.
- Distribucion: build de apoyo / donativos.
- Codigo fuente completo: no publicado en este repositorio publico.

Este repositorio mantiene publica la documentacion de la placa de repuesto ACT Labs REX y el firmware PS1 disponible.

## Plan de pruebas publico PS1

1. Verificar alimentacion y GND comun con consola.
2. Capturar ATT, CLK, CMD, DATA y ACK con analizador logico.
3. Confirmar respuesta base `0x41 0x5A`.
4. Validar que DATA quede estable antes del flanco esperado de CLK.
5. Ajustar pulso ACK hasta que la consola reconozca el control.
6. Probar botones uno por uno.
7. Activar AutoFire y confirmar alternancia de 50 ms ON / 50 ms OFF.

## Riesgos

- Timing estricto de ACK.
- Direccion de DATA y niveles electricos.
- Ruido o pull-up insuficiente en lineas de protocolo.
- El soporte PS2 completo queda fuera del firmware PS1 publico y se maneja como build Hybrid AUTO de apoyo.

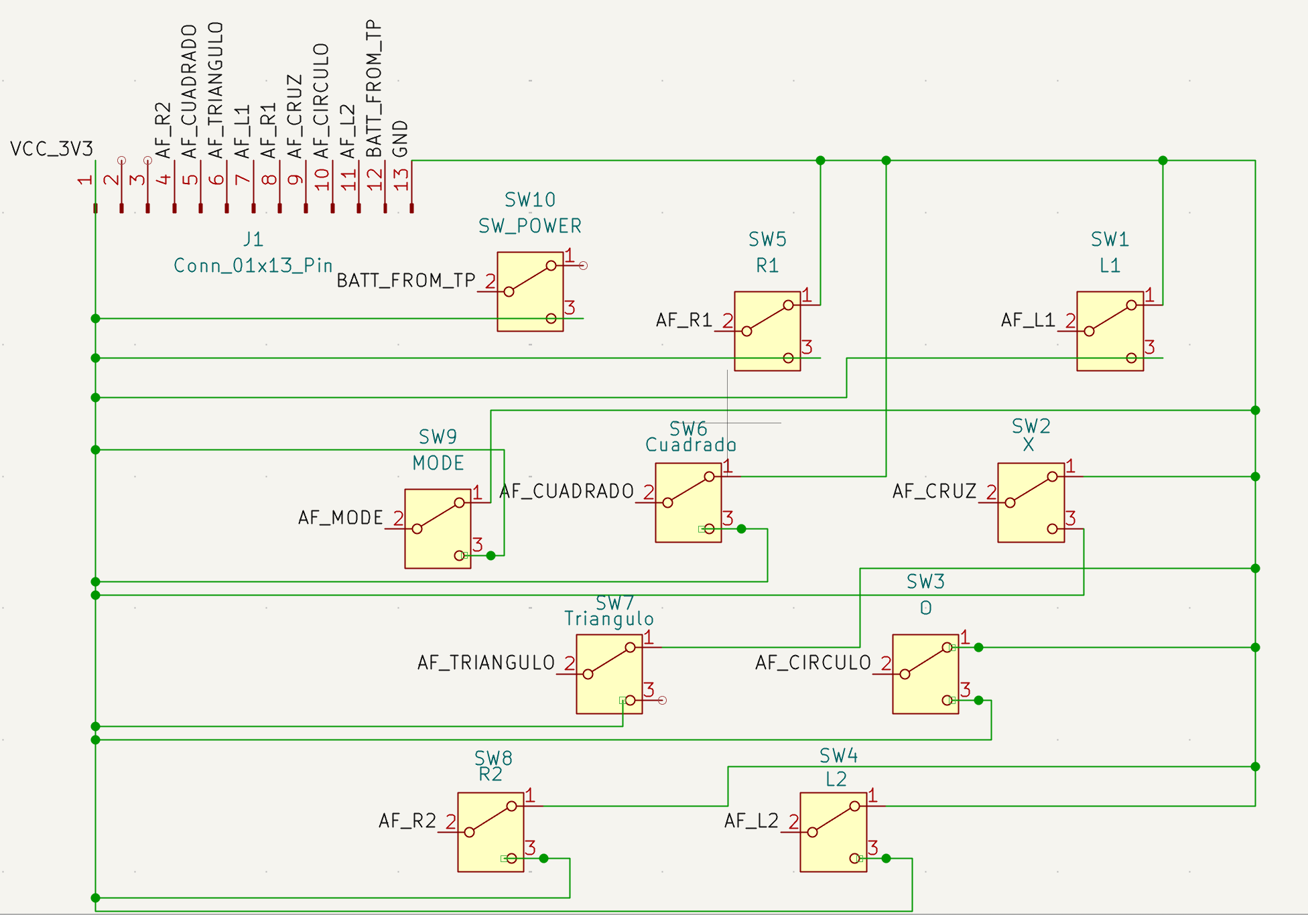
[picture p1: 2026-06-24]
hardware/images/SW_part.png

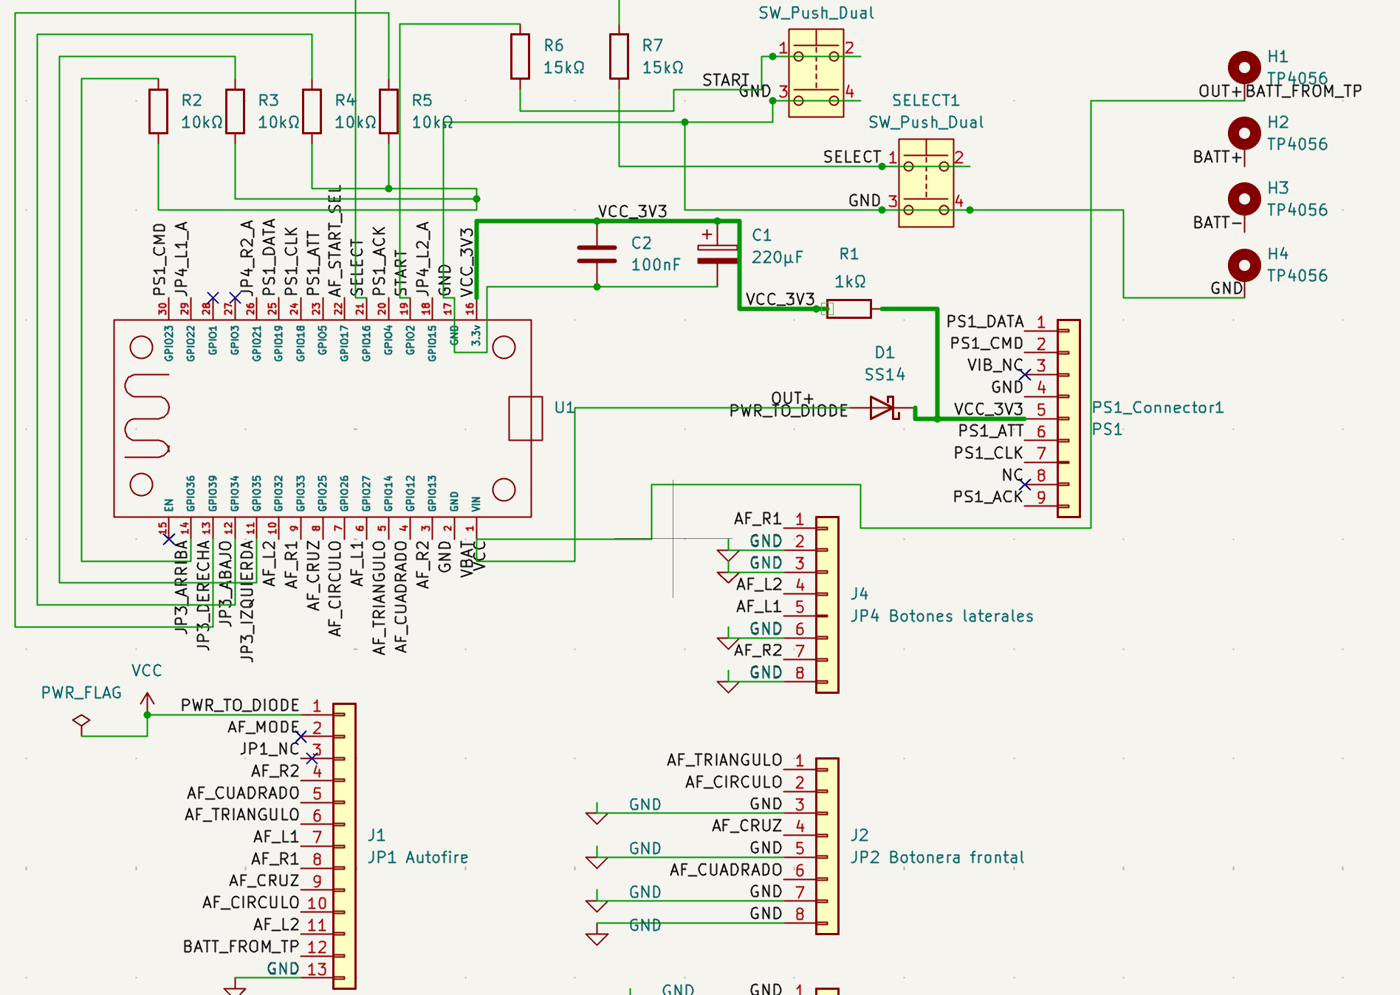
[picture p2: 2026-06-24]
hardware/images/Partcial_SCHM.png

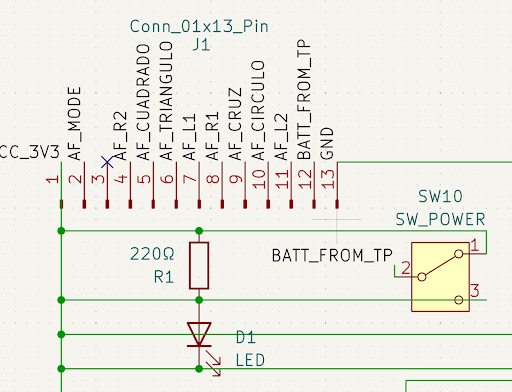
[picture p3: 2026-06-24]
hardware/images/Led-Switch.png

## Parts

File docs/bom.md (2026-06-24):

# BOM V2

BOM consolidado a partir de los CSV exportados desde KiCad.

## Placa principal `ACT_Labs_REX`

Archivo fuente: `hardware/fabrication/ACT_Labs_REX_BOM.csv`.

| Cant. | Referencias | Valor / parte | Footprint |
|---:|---|---|---|
| 1 | C1 | 220µF | `Capacitor_THT:CP_Radial_D6.3mm_P2.50mm` |
| 1 | C2 | 100nF | `Capacitor_THT:C_Disc_D3.0mm_W1.6mm_P2.50mm` |
| 2 | C3, C4 | 10µF | `Capacitor_THT:CP_Radial_D6.3mm_P2.50mm` |
| 2 | D1, D3 | SS14 | `Diode_SMD:D_SMA` |
| 1 | D2 | LED | `LED_THT:LED_D3.0mm` |
| 1 | J1 | PS1_Connector1 | `Connector_PinHeader_2.54mm:PinHeader_1x09_P2.54mm_Vertical` |
| 1 | J2 | JP1 Autofire | `Connector_PinHeader_2.54mm:PinHeader_1x13_P2.54mm_Vertical` |
| 1 | J3 | JP3 Palanca Direccional | `Connector_PinHeader_2.54mm:PinHeader_1x08_P2.54mm_Vertical` |
| 1 | J4 | JP4 Botones Frontales | `Connector_PinHeader_2.54mm:PinHeader_1x08_P2.54mm_Vertical` |
| 1 | J5 | JP5 Botones laterales | `Connector_PinHeader_2.54mm:PinHeader_1x08_P2.54mm_Vertical` |
| 1 | J6 | JP6 Autofire | `Connector_PinHeader_2.54mm:PinHeader_1x13_P2.54mm_Vertical` |
| 5 | R1, R2, R3, R4, R5 | 10kΩ | `Resistor_THT:R_Axial_DIN0207_L6.3mm_D2.5mm_P7.62mm_Horizontal` |
| 2 | R6, R7 | 4.7kΩ | `Resistor_THT:R_Axial_DIN0207_L6.3mm_D2.5mm_P7.62mm_Horizontal` |
| 1 | R8 | 220Ω | `Resistor_THT:R_Axial_DIN0207_L6.3mm_D2.5mm_P7.62mm_Horizontal` |
| 2 | Select1, Start1 | SW_Omron_B3FS | `Button_Switch_THT:SW_SPST_Omron_B3F-50xx` |
| 10 | SW1–SW10 | SW_SPDT | `Button_Switch_THT:Untitled_1` |
| 1 | U1 | ESP32 DevKit / 30 pin | `ESP32_Footprints:ESP32_30pin` |
| 1 | U2 | LD1117S33TR_SOT223 | `Package_TO_SOT_SMD:SOT-223-3_TabPin2` |

## Placa AutoFire

Archivo fuente: `hardware/fabrication/AutoFire_BOM.csv`.

| Cant. | Referencias | Valor / parte | Footprint |
|---:|---|---|---|
| 1 | D1 | LED | `LED_THT:LED_D3.0mm` |
| 1 | J1 | Conn_01x13 | `Connector_PinHeader_2.54mm:PinHeader_1x13_P2.54mm_Vertical` |
| 1 | R1 | 220Ω | `Resistor_THT:R_Axial_DIN0207_L6.3mm_D2.5mm_P7.62mm_Horizontal` |
| 10 | SW1–SW10 | SW_SPDT | `Button_Switch_THT:SW_CK_JS202011CQN_DPDT_Straight` |

## Cambios importantes frente a documentación previa

- `R6` y `R7` quedan en **4.7 kΩ** para DATA/ACK según BOM V2.
- La placa principal agrega `C3` y `C4` de **10µF**.
- La placa principal tiene dos Schottky: `D1` y `D3` como **SS14**.
- La placa principal incluye `U2` como **LD1117S33TR_SOT223**.
- Los archivos POS indican 40 componentes en placa principal: 27 en top y 13 en bottom.
- La placa AutoFire tiene 13 componentes, todos en top.

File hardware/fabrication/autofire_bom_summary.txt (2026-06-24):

AutoFire BOM V2

D1 LED quantity 1
J1 connector 1x13 quantity 1
R1 220 ohm quantity 1
SW1 to SW10 SPDT switches quantity 10 total

Source file uploaded: AutoFire_BOM.csv

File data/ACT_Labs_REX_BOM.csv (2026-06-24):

Reference | Value | Footprint | Datasheet | QUANTITY
C1 | 220µF | Capacitor_THT:CP_Radial_D6.3mm_P2.50mm |  | 1
C2 | 100nF | Capacitor_THT:C_Disc_D3.0mm_W1.6mm_P2.50mm |  | 1
C3 | 10µF | Capacitor_THT:CP_Radial_D6.3mm_P2.50mm |  | 1
C4 | 10µF | Capacitor_THT:CP_Radial_D6.3mm_P2.50mm |  | 1
D1 | SS14 | Diode_SMD:D_SMA | https://www.vishay.com/docs/88746/ss12.pdf | 1
D2 | LED | LED_THT:LED_D3.0mm |  | 1
D3 | SS14 | Diode_SMD:D_SMA | https://www.vishay.com/docs/88746/ss12.pdf | 1
J1 | PS1_Connector1 | Connector_PinHeader_2.54mm:PinHeader_1x09_P2.54mm_Vertical |  | 1
J2 | JP1 Autofire | Connector_PinHeader_2.54mm:PinHeader_1x13_P2.54mm_Vertical |  | 1
J3 | JP3 Palanca Direccional | Connector_PinHeader_2.54mm:PinHeader_1x08_P2.54mm_Vertical |  | 1
J4 | JP4 Botones Frontales | Connector_PinHeader_2.54mm:PinHeader_1x08_P2.54mm_Vertical |  | 1
J5 | JP5 Botones laterales | Connector_PinHeader_2.54mm:PinHeader_1x08_P2.54mm_Vertical |  | 1
J6 | JP6 Autofire | Connector_PinHeader_2.54mm:PinHeader_1x13_P2.54mm_Vertical |  | 1
R1 | 10kΩ | Resistor_THT:R_Axial_DIN0207_L6.3mm_D2.5mm_P7.62mm_Horizontal |  | 1
R2 | 10kΩ | Resistor_THT:R_Axial_DIN0207_L6.3mm_D2.5mm_P7.62mm_Horizontal |  | 1
R3 | 10kΩ | Resistor_THT:R_Axial_DIN0207_L6.3mm_D2.5mm_P7.62mm_Horizontal |  | 1
R4 | 10kΩ | Resistor_THT:R_Axial_DIN0207_L6.3mm_D2.5mm_P7.62mm_Horizontal |  | 1
R5 | 10kΩ | Resistor_THT:R_Axial_DIN0207_L6.3mm_D2.5mm_P7.62mm_Horizontal |  | 1
R6 | 4.7kΩ | Resistor_THT:R_Axial_DIN0207_L6.3mm_D2.5mm_P7.62mm_Horizontal |  | 1
R7 | 4.7kΩ | Resistor_THT:R_Axial_DIN0207_L6.3mm_D2.5mm_P7.62mm_Horizontal |  | 1
R8 | 220Ω | Resistor_THT:R_Axial_DIN0207_L6.3mm_D2.5mm_P7.62mm_Horizontal |  | 1
Select1 | SW_Omron_B3FS | Button_Switch_THT:SW_SPST_Omron_B3F-50xx | https://omronfs.omron.com/en_US/ecb/products/pdf/en-b3fs.pdf | 1
Start1 | SW_Omron_B3FS | Button_Switch_THT:SW_SPST_Omron_B3F-50xx | https://omronfs.omron.com/en_US/ecb/products/pdf/en-b3fs.pdf | 1
SW1 | SW_SPDT | Button_Switch_THT:Untitled_1 |  | 1
SW2 | SW_SPDT | Button_Switch_THT:Untitled_1 |  | 1
SW3 | SW_SPDT | Button_Switch_THT:Untitled_1 |  | 1
SW4 | SW_SPDT | Button_Switch_THT:Untitled_1 |  | 1
SW5 | SW_SPDT | Button_Switch_THT:Untitled_1 |  | 1
SW6 | SW_SPDT | Button_Switch_THT:Untitled_1 |  | 1
SW7 | SW_SPDT | Button_Switch_THT:Untitled_1 |  | 1
SW8 | SW_SPDT | Button_Switch_THT:Untitled_1 |  | 1
SW9 | SW_SPDT | Button_Switch_THT:Untitled_1 |  | 1
SW10 | SW_SPDT | Button_Switch_THT:Untitled_1 |  | 1
U1 |  | ESP32_Footprints:ESP32_30pin |  | 1
U2 | LD1117S33TR_SOT223 | Package_TO_SOT_SMD:SOT-223-3_TabPin2 | http://www.st.com/st-web-ui/static/active/en/resource/technical/document/datasheet/CD00000544.pdf | 1

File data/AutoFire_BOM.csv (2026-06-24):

Reference | Value | Footprint | Datasheet | QUANTITY
D1 | LED | LED_THT:LED_D3.0mm |  | 1
J1 | Conn_01x13 | Connector_PinHeader_2.54mm:PinHeader_1x13_P2.54mm_Vertical |  | 1
R1 | 220Ω | Resistor_THT:R_Axial_DIN0207_L6.3mm_D2.5mm_P7.62mm_Horizontal |  | 1
SW1 | SW_SPDT | Button_Switch_THT:SW_CK_JS202011CQN_DPDT_Straight |  | 1
SW2 | SW_SPDT | Button_Switch_THT:SW_CK_JS202011CQN_DPDT_Straight |  | 1
SW3 | SW_SPDT | Button_Switch_THT:SW_CK_JS202011CQN_DPDT_Straight |  | 1
SW4 | SW_SPDT | Button_Switch_THT:SW_CK_JS202011CQN_DPDT_Straight |  | 1
SW5 | SW_SPDT | Button_Switch_THT:SW_CK_JS202011CQN_DPDT_Straight |  | 1
SW6 | SW_SPDT | Button_Switch_THT:SW_CK_JS202011CQN_DPDT_Straight |  | 1
SW7 | SW_SPDT | Button_Switch_THT:SW_CK_JS202011CQN_DPDT_Straight |  | 1
SW8 | SW_SPDT | Button_Switch_THT:SW_CK_JS202011CQN_DPDT_Straight |  | 1
SW9 | SW_SPDT | Button_Switch_THT:SW_CK_JS202011CQN_DPDT_Straight |  | 1
SW10 | SW_SPDT | Button_Switch_THT:SW_CK_JS202011CQN_DPDT_Straight |  | 1

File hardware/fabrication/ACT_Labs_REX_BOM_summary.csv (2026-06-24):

Reference | Value | Quantity
C1 | 220uF | 1
C2 | 100nF | 1
C3 | 10uF | 1
C4 | 10uF | 1
D1 | SS14 | 1
D2 | LED | 1
D3 | SS14 | 1
J1 | PS1_Connector1 | 1
J2 | JP1_Autofire | 1
J3 | JP3_Palanca_Direccional | 1
J4 | JP4_Botones_Frontales | 1
J5 | JP5_Botones_laterales | 1
J6 | JP6_Autofire | 1
R1 | 10k | 1
R2 | 10k | 1
R3 | 10k | 1
R4 | 10k | 1
R5 | 10k | 1
R6 | 4.7k | 1
R7 | 4.7k | 1
R8 | 220R | 1
Select1 | SW_Omron_B3FS | 1
Start1 | SW_Omron_B3FS | 1
SW1 | SW_SPDT | 1
SW2 | SW_SPDT | 1
SW3 | SW_SPDT | 1
SW4 | SW_SPDT | 1
SW5 | SW_SPDT | 1
SW6 | SW_SPDT | 1
SW7 | SW_SPDT | 1
SW8 | SW_SPDT | 1
SW9 | SW_SPDT | 1
SW10 | SW_SPDT | 1
U1 | ESP32_30pin | 1
U2 | LD1117S33TR_SOT223 | 1

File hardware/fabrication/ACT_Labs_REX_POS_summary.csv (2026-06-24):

Ref | Value | Side
C1 | 220uF | bottom
C3 | 10uF | bottom
C4 | 10uF | bottom
D1 | SS14 | bottom
D3 | SS14 | bottom
J6 | JP6_Autofire | bottom
JP1 | SolderJumper_2_Open | bottom
JP2 | SolderJumper_2_Open | bottom
JP3 | SolderJumper_2_Open | bottom
R1 | 10k | bottom
R8 | 220R | bottom
Select1 | SW_Omron_B3FS | bottom
Start1 | SW_Omron_B3FS | bottom
C2 | 100nF | top
D2 | LED | top
H1 | TP4056 | top
H2 | TP4056 | top
J1 | PS1_Connector1 | top
J2 | JP1_Autofire | top
J3 | JP3_Palanca_Direccional | top
J4 | JP4_Botones_Frontales | top
J5 | JP5_Botones_laterales | top
R2 | 10k | top
R3 | 10k | top
R4 | 10k | top
R5 | 10k | top
R6 | 4.7k | top
R7 | 4.7k | top
SW1 | SW_SPDT | top
SW2 | SW_SPDT | top
SW3 | SW_SPDT | top
SW4 | SW_SPDT | top
SW5 | SW_SPDT | top
SW6 | SW_SPDT | top
SW7 | SW_SPDT | top
SW8 | SW_SPDT | top
SW9 | SW_SPDT | top
SW10 | SW_SPDT | top
U1 | ESP32_30pin | top
U2 | LD1117S33TR_SOT223 | top

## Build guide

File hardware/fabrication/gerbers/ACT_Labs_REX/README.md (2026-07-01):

# ACT Labs REX Gerbers

Gerbers exportados desde KiCad para **ACT Labs REX PCB V2.2**.

## Uso

Esta carpeta es para fabricacion de PCB.

Para editar el proyecto usar:

```text
hardware/kicad/ACT_Labs_REX/
```

## Archivos esperados

| Archivo | Funcion |
|---|---|
| ACT_Labs_REX-F_Cu.gbr | Cobre superior |
| ACT_Labs_REX-B_Cu.gbr | Cobre inferior |
| ACT_Labs_REX-F_Mask.gbr | Mascara superior |
| ACT_Labs_REX-B_Mask.gbr | Mascara inferior |
| ACT_Labs_REX-F_Paste.gbr | Pasta superior |
| ACT_Labs_REX-B_Paste.gbr | Pasta inferior |
| ACT_Labs_REX-F_Silkscreen.gbr | Serigrafia superior |
| ACT_Labs_REX-B_Silkscreen.gbr | Serigrafia inferior |
| ACT_Labs_REX-Edge_Cuts.gbr | Contorno PCB |
| ACT_Labs_REX-PTH.drl | Taladros metalizados |
| ACT_Labs_REX-NPTH.drl | Taladros no metalizados |
| ACT_Labs_REX-job.gbrjob | Job file de fabricacion |

## Datos del job file

- Generado por KiCad / Pcbnew 10.0.3.
- Revision del proyecto: 2.2.
- Capas: 2.
- Grosor: 1.6 mm.
- Tamano reportado: 138.9318 mm x 120.15 mm.

## Checklist antes de fabricar

- [ ] Abrir `ACT_Labs_REX-job.gbrjob` o el ZIP de gerbers en un visor Gerber.
- [ ] Confirmar contorno `Edge_Cuts`.
- [ ] Confirmar taladros PTH y NPTH.
- [ ] Confirmar orientacion de silkscreen.
- [ ] Confirmar que los archivos son de la revision correcta.
- [ ] Confirmar corto START/SELECT antes de ordenar nueva fabricacion.

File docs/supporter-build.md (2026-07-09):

# Firmware Hybrid AUTO - Build de apoyo

## Resumen

La build **Hybrid AUTO** es una version avanzada del firmware para ESP32 DevKit V1 orientada a usuarios que quieran apoyar el desarrollo del proyecto.

Esta build agrega deteccion automatica y soporte para:

- PS1 cableado.
- PS2 / DualShock cableado.
- Bluetooth BLE HID.
- AutoFire / turbo segun configuracion de la placa.

El firmware PS1 publico se mantiene disponible gratuitamente en este repositorio. La build Hybrid AUTO se maneja como opcion de apoyo/donativos para sostener el desarrollo, pruebas, documentacion y fabricacion de prototipos.

## Alcance

| Funcion | Estado |
|---|---|
| PS1 digital cableado | Listo |
| PS2 / DualShock | Listo |
| Bluetooth BLE HID | Listo |
| Deteccion automatica PS1 / PS2 / BLE | Listo |
| AutoFire | Integrado / sujeto a validacion fisica |

## Distribucion

El repositorio publico incluye:

- Hardware KiCad.
- Documentacion.
- Gerbers cuando esten validados.
- Firmware PS1 publico.
- Guias de prueba y fabricacion.

La build Hybrid AUTO se distribuye por separado como apoyo/donativo. La distribucion recomendada es publicar o entregar:

```text
Act_Labs_Hybrid_AUTO_vX.X.bin
checksums.txt
flashing_guide.md
release_notes.md
```

No se recomienda publicar el codigo fuente completo del firmware Hybrid AUTO en este repositorio publico si se desea mantenerlo como build de apoyo.

## Recomendaciones para publicar la build

Antes de entregar una build de apoyo:

1. Compilar una version estable del binario.
2. Probar PS1 en consola real.
3. Probar PS2 en consola real.
4. Probar BLE en PC o Android.
5. Generar checksums SHA256 y MD5.
6. Documentar version, fecha, hardware objetivo y cambios.
7. Incluir instrucciones de flasheo.

## Plataformas sugeridas

- GitHub Pages como landing page.
- PayPal / Mercado Pago para apoyo directo.
- Gumroad / Payhip / Ko-fi para entrega de archivo digital.
- Stripe Payment Links para pagos simples.
- GitHub Sponsors para apoyo recurrente.

## Nota de licencia y dependencias

Antes de distribuir binarios cerrados o semi-cerrados, revisar las licencias de las librerias usadas por el firmware.

Si alguna dependencia exige publicacion de fuente o avisos de licencia, incluir esos avisos junto con la build.

## Mensaje sugerido para usuarios

```text
El firmware PS1 publico esta disponible gratis en GitHub.

La build Hybrid AUTO PS1/PS2/BLE es una version avanzada para quienes quieran apoyar el desarrollo del proyecto. Tu apoyo ayuda a cubrir prototipos, pruebas en hardware real, documentacion y nuevas revisiones de PCB.
```

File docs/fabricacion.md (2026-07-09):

# Fabricación V2

Archivos KiCad actualizados para la revisión V2. Los Gerbers quedan pendientes de regenerar desde la revisión KiCad actual antes de enviar a fabricación.

## Estado actual

| Área | Estado |
|---|---|
| KiCad principal | Actualizado en `hardware/kicad/ACT_Labs_REX/` |
| Gerbers principal | Pendientes de regenerar |
| BOM/POS | Revalidar después de regenerar Gerbers |
| Firmware PS1 | PS1 Digital v1.1 OK |

## Archivos CSV

| Archivo | Descripción |
|---|---|
| `hardware/fabrication/ACT_Labs_REX_BOM.csv` | Lista de materiales de la placa principal |
| `hardware/fabrication/ACT_Labs_REX_POS.csv` | Posiciones de componentes de la placa principal |
| `hardware/fabrication/AutoFire_BOM.csv` | Lista de materiales de la placa AutoFire |
| `hardware/fabrication/AutoFire_POS.csv` | Posiciones de componentes de la placa AutoFire |

## Resumen de placa principal `ACT_Labs_REX`

- Componentes relevantes: ESP32 DevKit V1, LD1117S33TR, TP4056 pads, SS14, LED, switches SPDT, START/SELECT Omron, conectores JP y PS1.
- START/SELECT deben validarse por continuidad: señal abierta sin presionar y continuidad a GND al presionar.
- El pinout PS1 debe mantenerse alineado con el firmware usado en pruebas.

## Resumen de placa AutoFire

- Componentes: 10 switches SPDT, LED, resistencia 220Ω y conector 1x13.
- Validar continuidad entre placa principal, placa AutoFire y conectores JP antes de energizar.

## Checklist antes de fabricar

1. Abrir `ACT_Labs_REX.kicad_pcb` y `AutoFire.kicad_pcb` en KiCad 10.
2. Ejecutar DRC y corregir warnings críticos.
3. Confirmar orientación de `D1`, `D3`, `U2`, `C1`, `C3` y `C4`.
4. Validar START/SELECT con multímetro: abierto sin presionar y continuidad a GND al presionar.
5. Revisar footprints `Button_Switch_THT:Untitled_1` de los SPDT de la placa principal.
6. Revisar el footprint `SW_CK_JS202011CQN_DPDT_Straight` en AutoFire.
7. Regenerar Gerbers, BOM y POS desde la misma revisión antes de enviar a fabricación.
8. Confirmar que las unidades del POS sean compatibles con el ensamblador.
9. Abrir Gerbers nuevos en visualizador externo antes de ordenar PCB.

## Observaciones

- La placa principal mezcla componentes top y bottom; esto puede afectar ensamble manual o pick-and-place.
- La placa AutoFire es más simple: todos los componentes están en top.
- La documentación de BOM en `docs/bom.md` está resumida; los CSV son la fuente exacta para fabricación.
- Los Gerbers existentes pueden estar desfasados frente a los archivos KiCad actuales hasta que se suba la nueva exportación.

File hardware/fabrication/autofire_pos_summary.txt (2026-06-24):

AutoFire POS V2

All components are on top side.

D1 LED
J1 connector 1x13
R1 220 ohm
SW1 to SW10 SPDT switches

Source file uploaded: AutoFire_POS.csv

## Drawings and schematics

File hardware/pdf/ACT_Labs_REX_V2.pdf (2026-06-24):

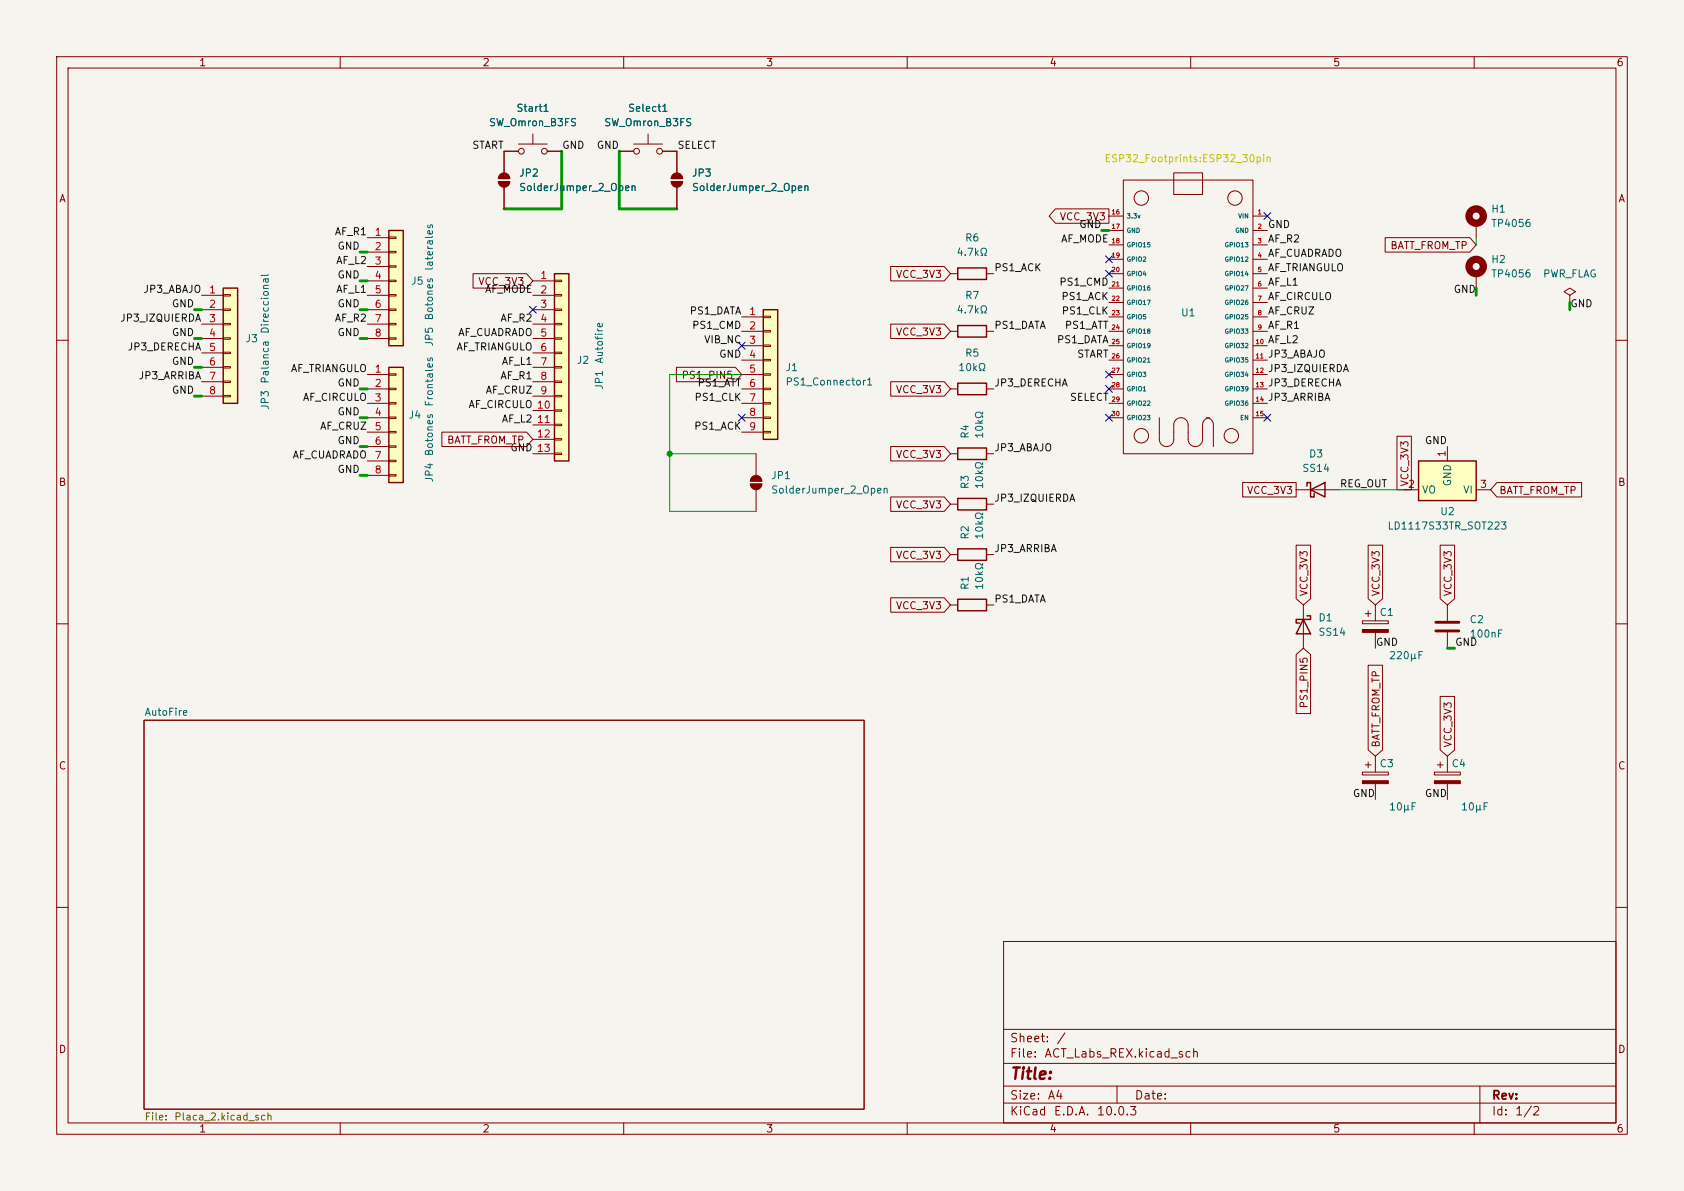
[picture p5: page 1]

Size: A4 | Rev:
KiCad E.D.A. 10.0.3 | Id: 1/2

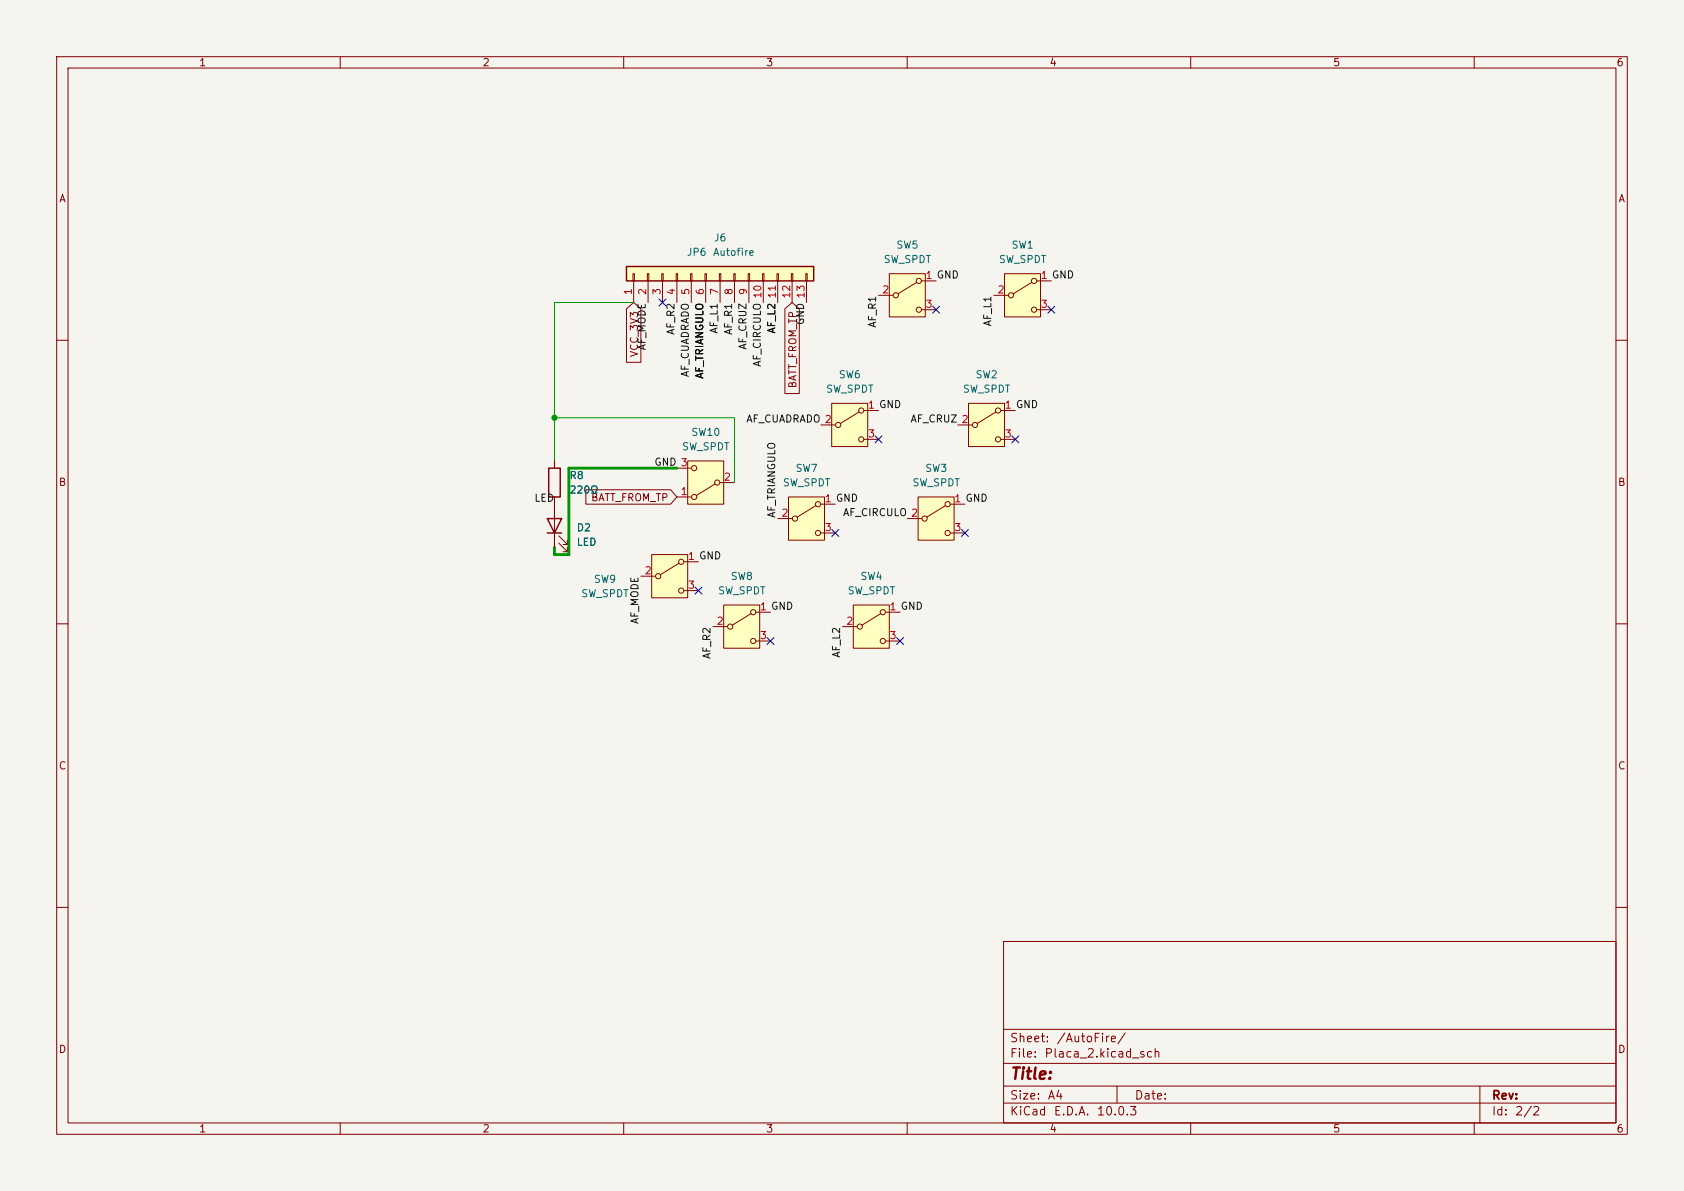
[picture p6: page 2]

Size: A4 | Rev:
KiCad E.D.A. 10.0.3 | Id: 2/2

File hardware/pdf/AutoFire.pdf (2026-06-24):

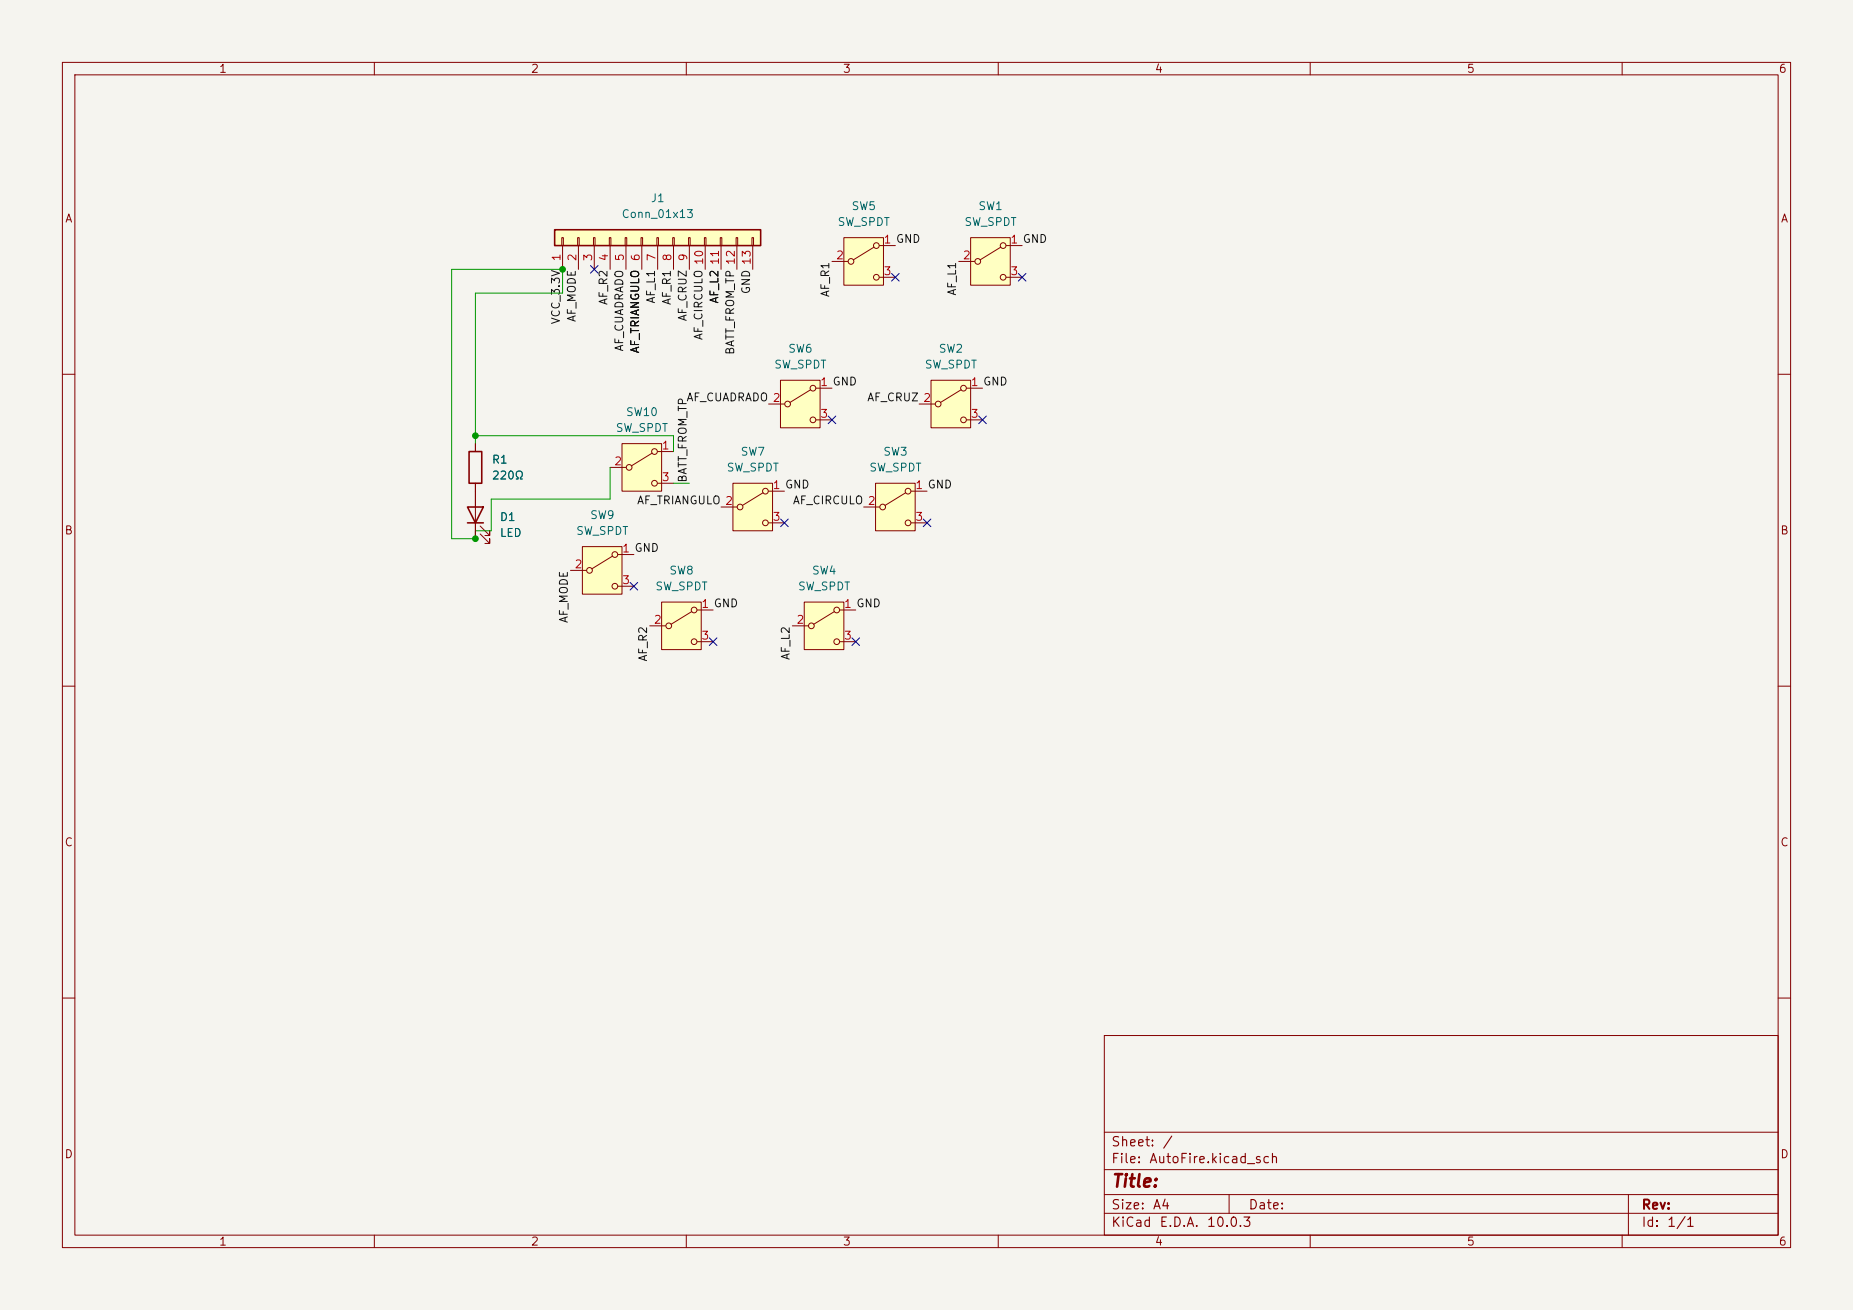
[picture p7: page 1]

Size: A4 | Rev:
KiCad E.D.A. 10.0.3 | Id: 1/1

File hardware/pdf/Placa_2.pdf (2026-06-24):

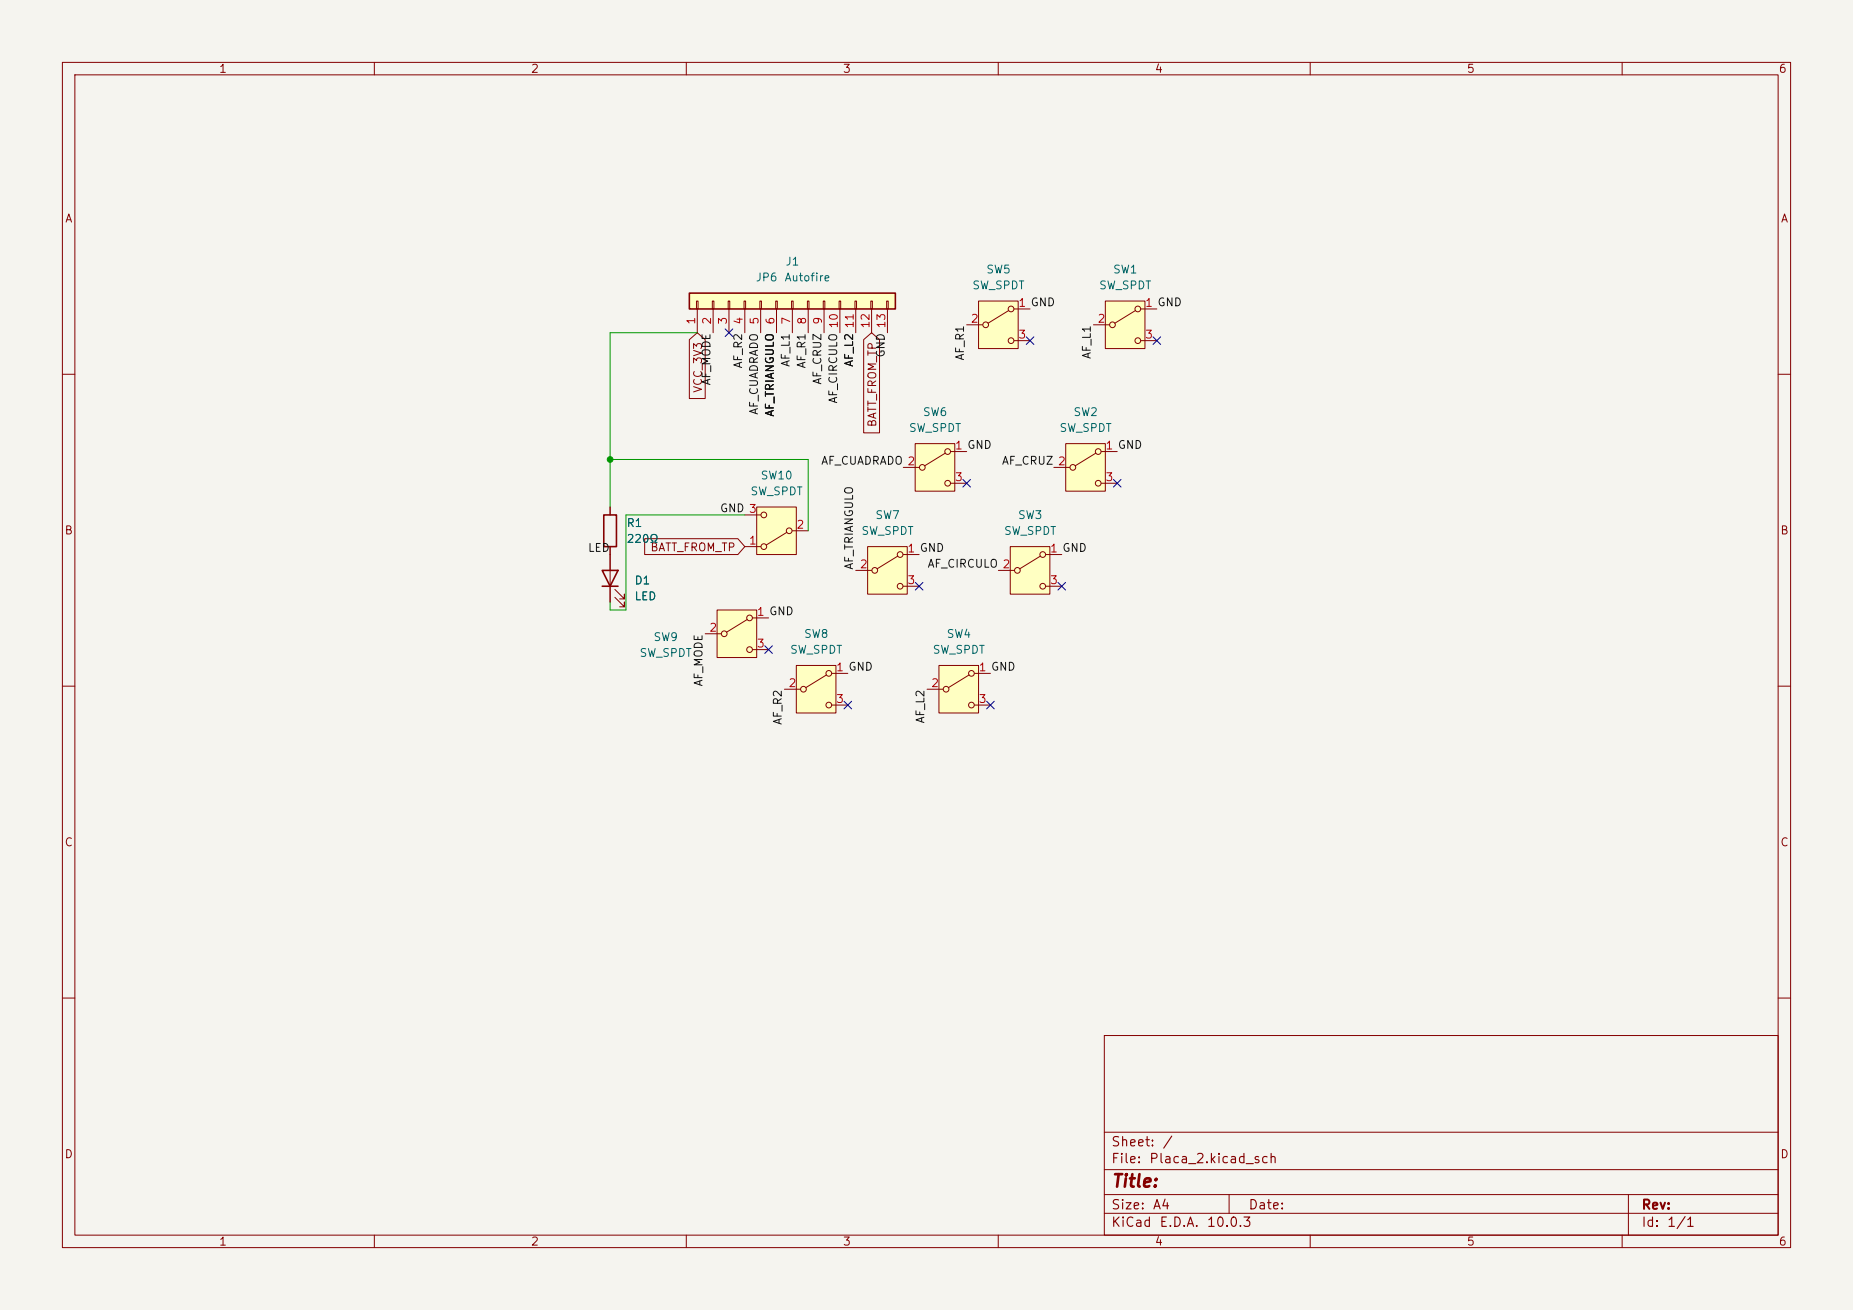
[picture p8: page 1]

Size: A4 | Rev:
KiCad E.D.A. 10.0.3 | Id: 1/1

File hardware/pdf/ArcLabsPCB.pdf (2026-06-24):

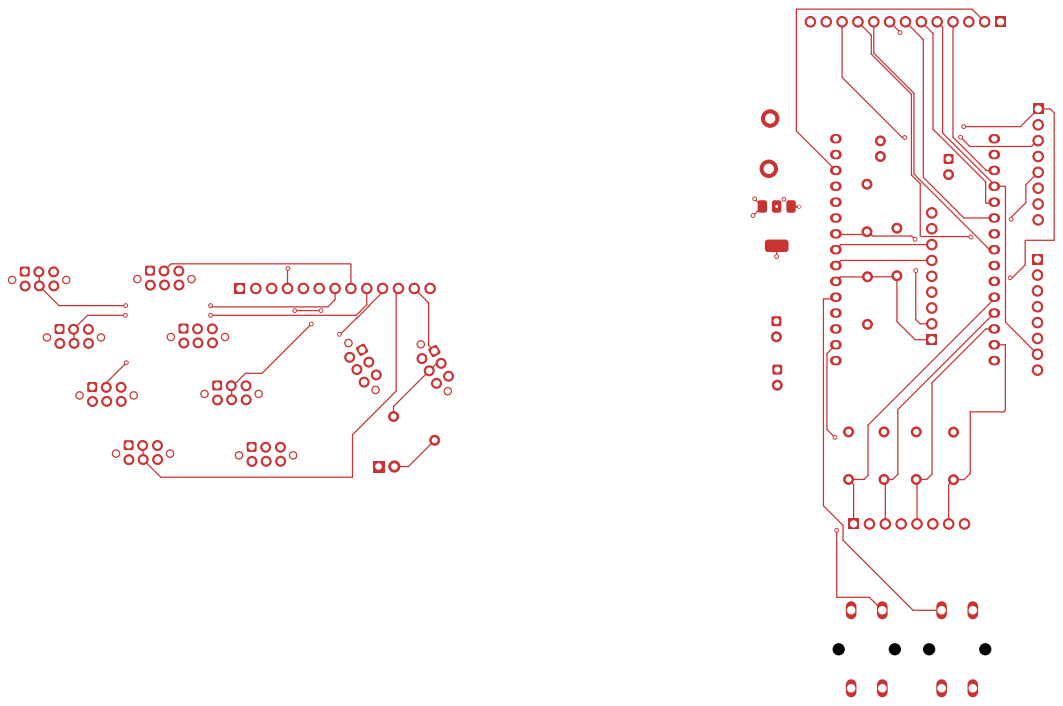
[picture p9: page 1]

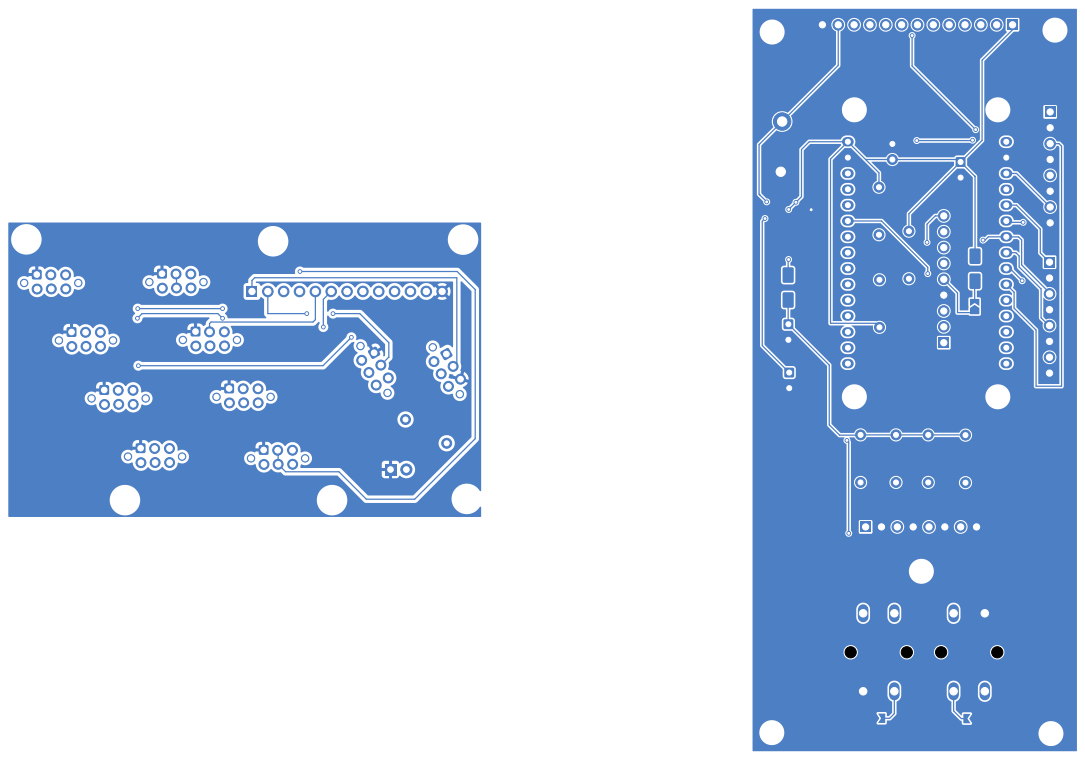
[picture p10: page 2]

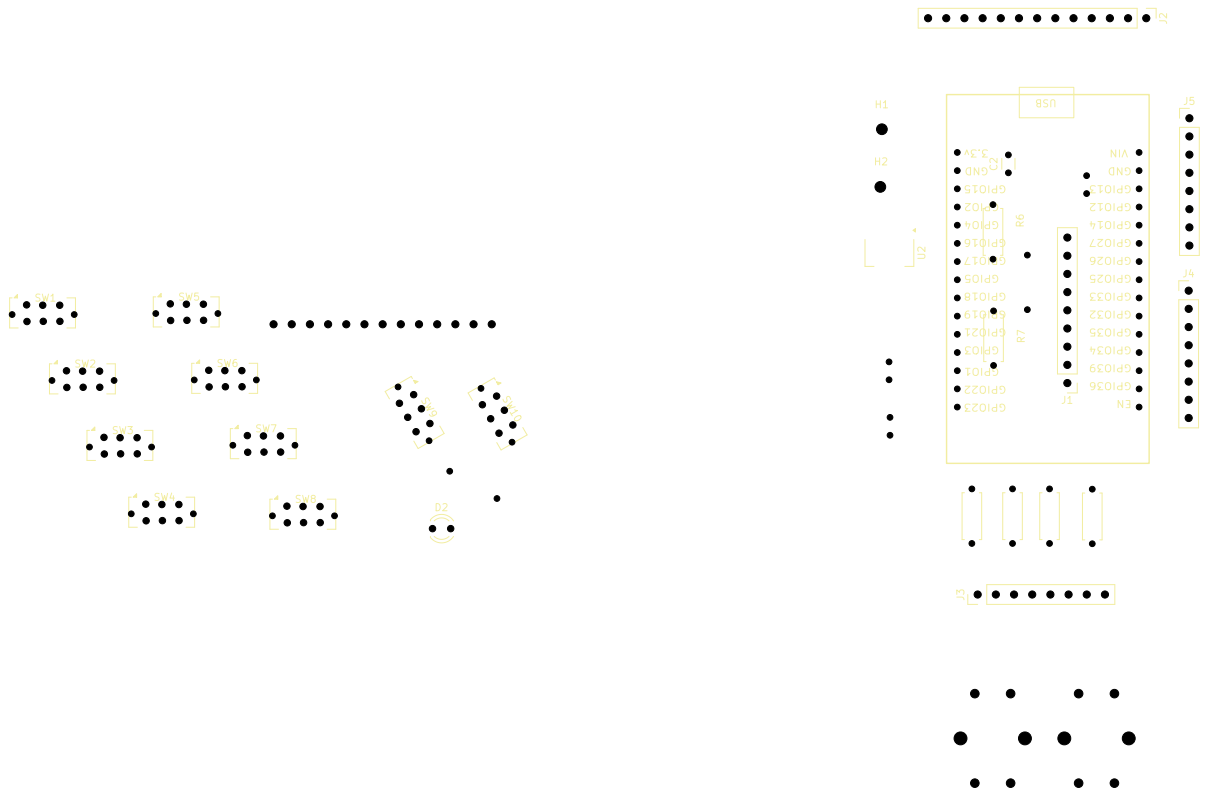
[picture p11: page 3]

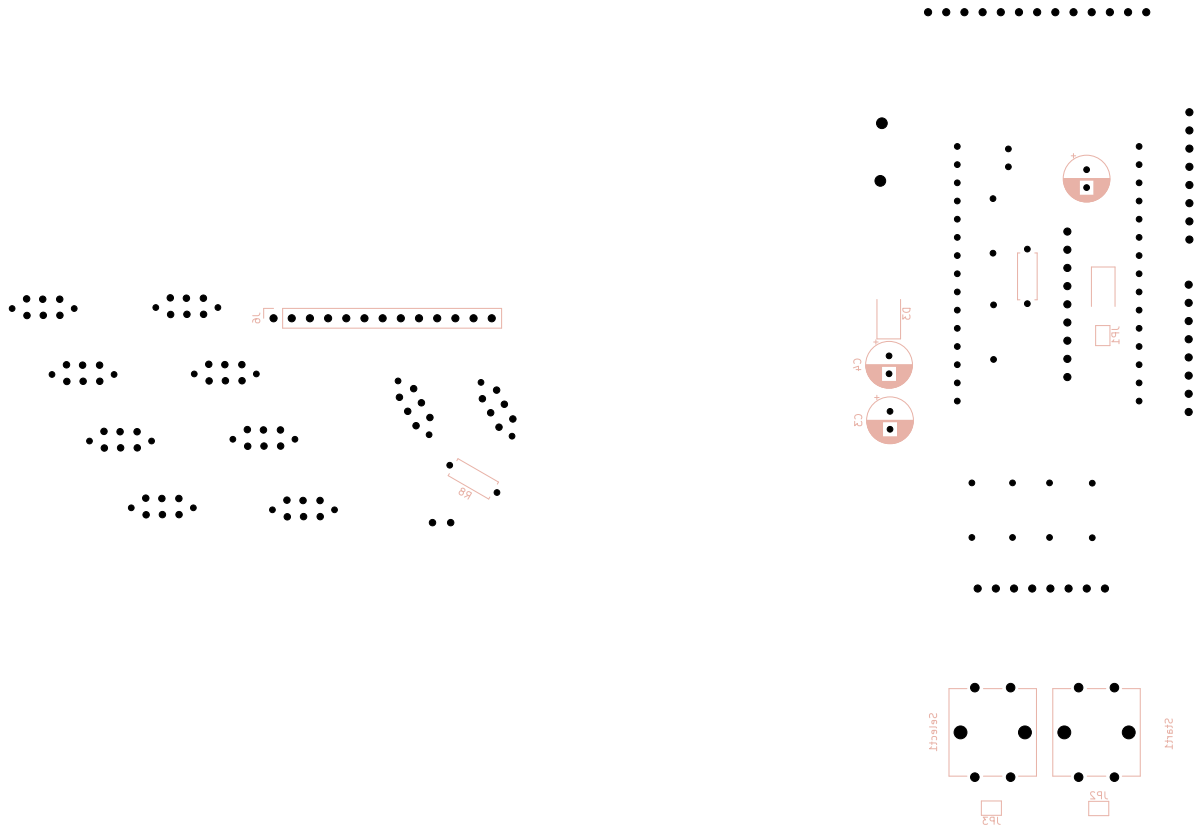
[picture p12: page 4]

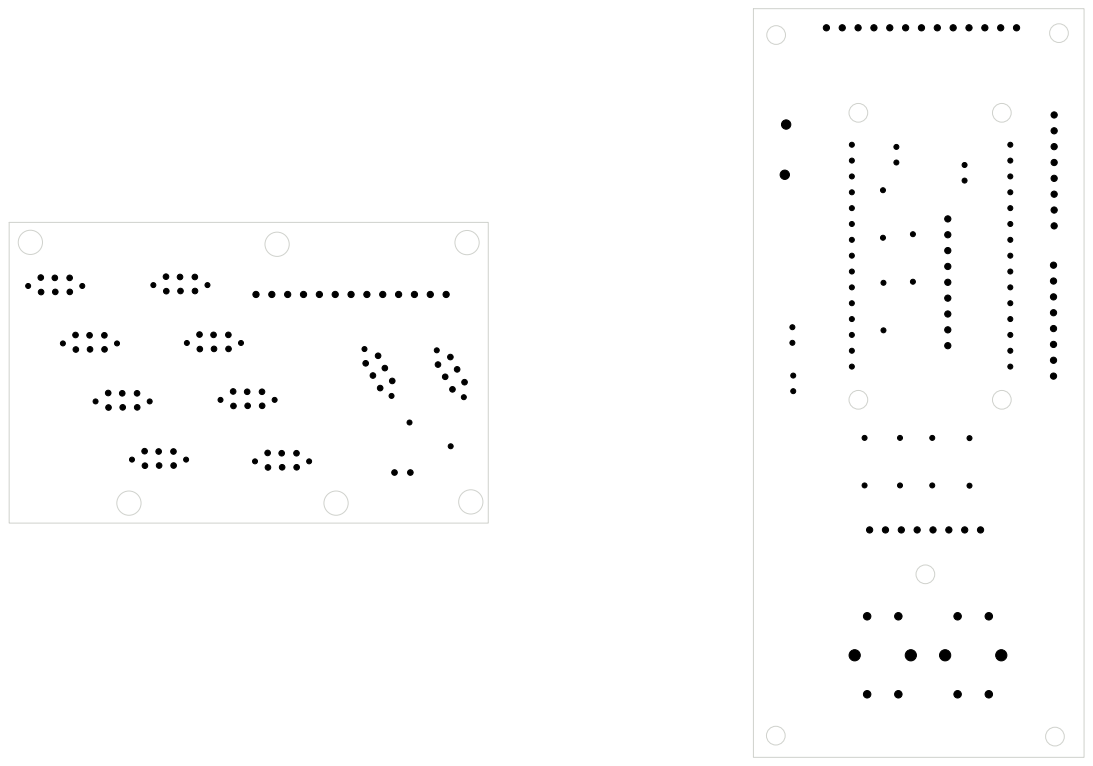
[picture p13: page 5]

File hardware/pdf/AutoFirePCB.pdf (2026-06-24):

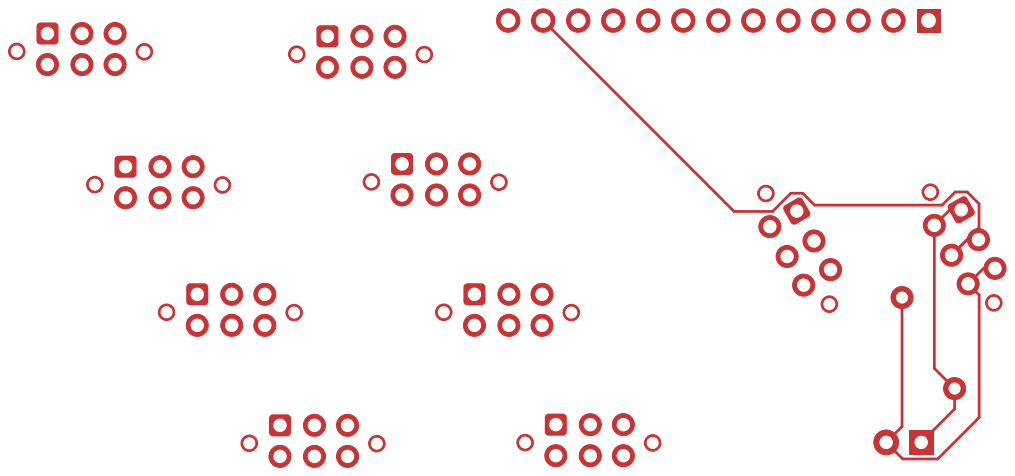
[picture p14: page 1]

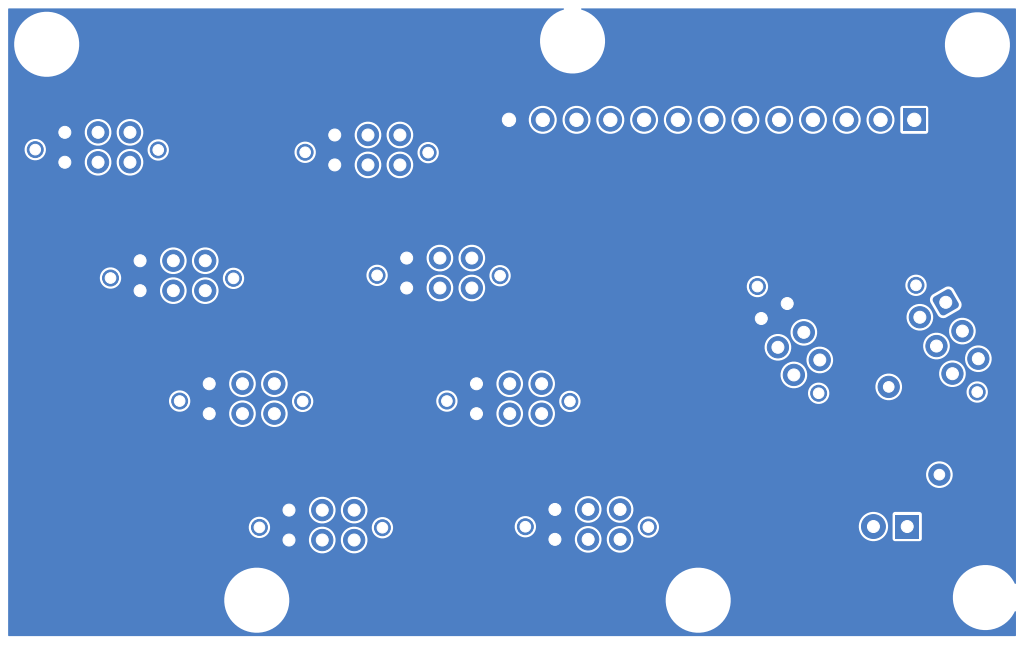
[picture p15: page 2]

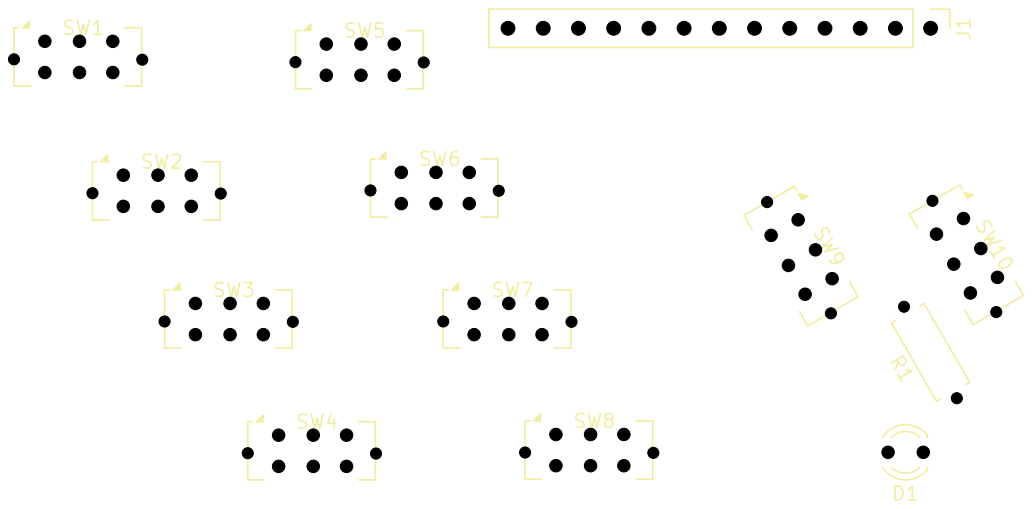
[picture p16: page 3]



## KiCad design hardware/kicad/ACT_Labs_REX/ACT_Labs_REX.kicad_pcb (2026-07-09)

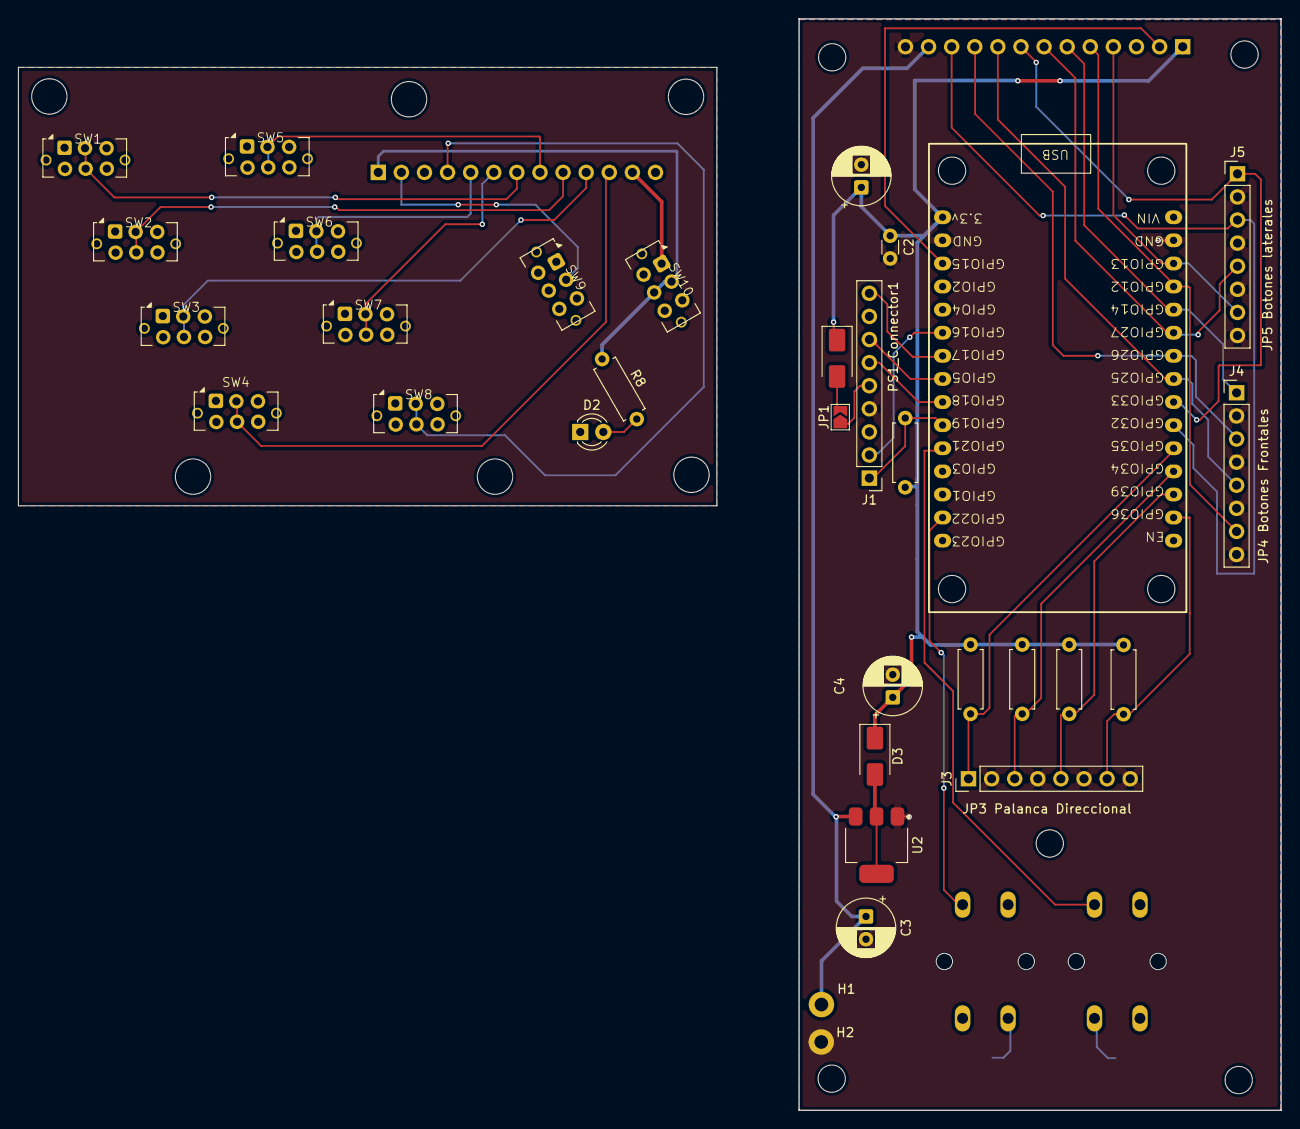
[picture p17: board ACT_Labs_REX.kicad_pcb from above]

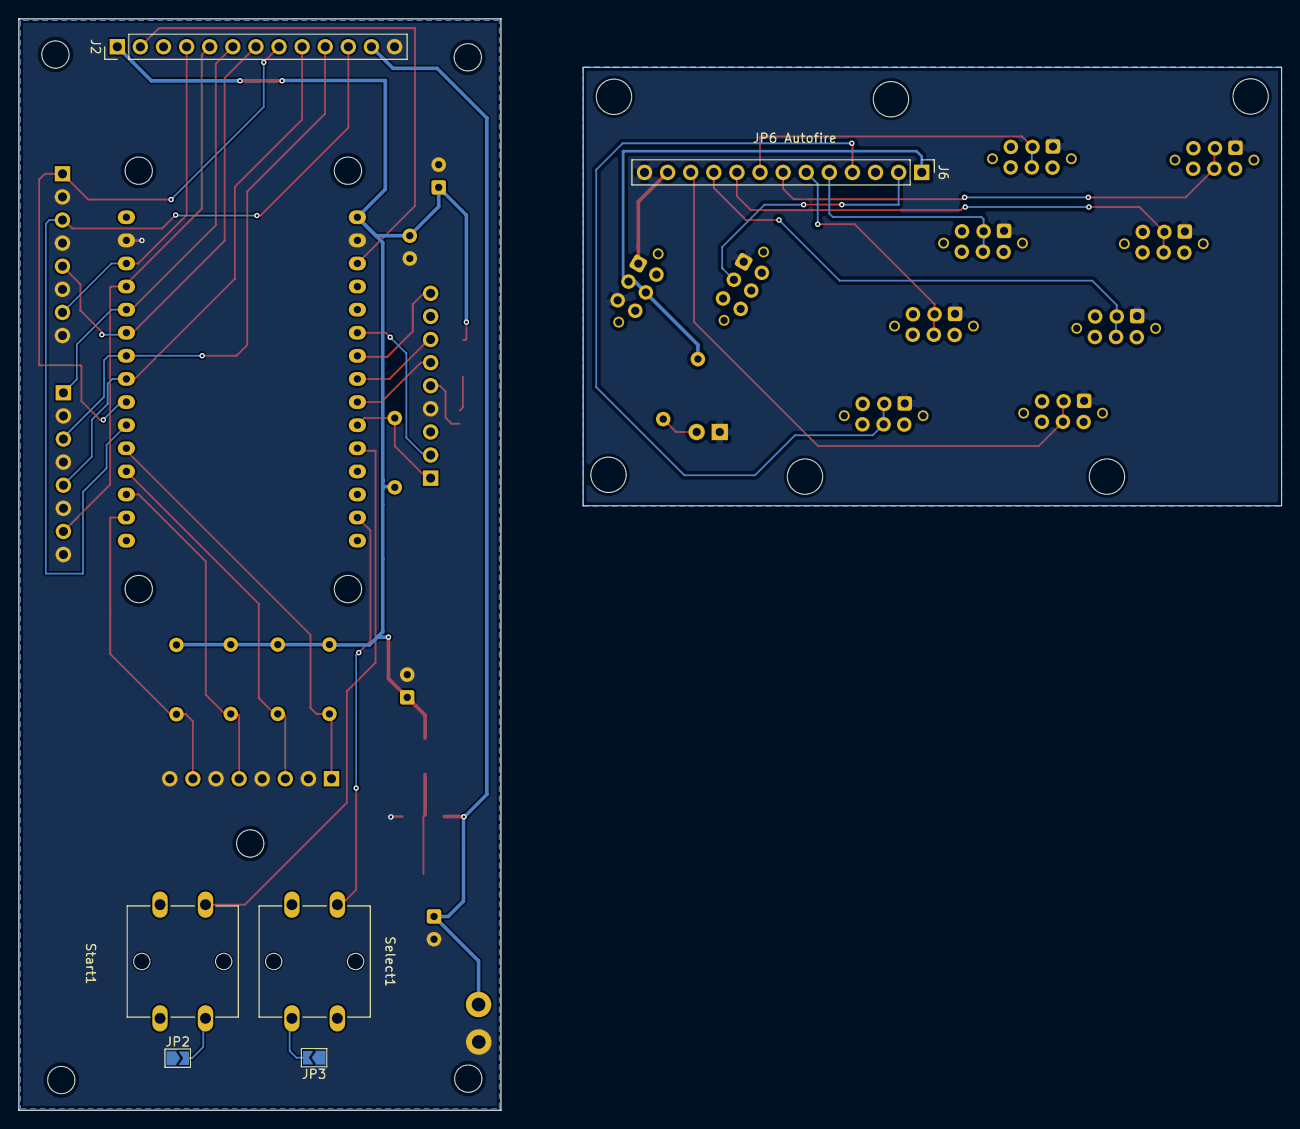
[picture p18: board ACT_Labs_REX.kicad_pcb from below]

Board: 2 copper layers, 138.8 x 120.0 mm, 38 parts (6 on the bottom side), 35 nets.

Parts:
C1: 220µF; CP_Radial_D6.3mm_P2.50mm
C2: 100nF; C_Disc_D3.0mm_W1.6mm_P2.50mm
C3, C4: 10µF; CP_Radial_D6.3mm_P2.50mm
D1, D3: SS14; D_SMA
D2: LED; LED_D3.0mm
H1, H2: TP4056; MountingHole_2.5mm_Pad
J1: PS1_Connector1; PinHeader_1x09_P2.54mm_Vertical
J2: JP1 Autofire; PinHeader_1x13_P2.54mm_Vertical
J3: JP3 Palanca Direccional; PinHeader_1x08_P2.54mm_Vertical
J4: JP4 Botones Frontales; PinHeader_1x08_P2.54mm_Vertical
J5: JP5 Botones laterales; PinHeader_1x08_P2.54mm_Vertical
J6: JP6 Autofire; PinHeader_1x13_P2.54mm_Vertical
JP1, JP2, JP3: SolderJumper_2_Open; SolderJumper-2_P1.3mm_Open_TrianglePad1.0x1.5mm
R1, R2, R3, R4, R5: 10kΩ; R_Axial_DIN0207_L6.3mm_D2.5mm_P7.62mm_Horizontal
R8: 220Ω; R_Axial_DIN0207_L6.3mm_D2.5mm_P7.62mm_Horizontal
SW1, SW2, SW3, SW4, SW5, SW6, SW7, SW8, SW9, SW10: SW_SPDT; Untitled_1
Select1: SW_Omron_B3FS; SW_SPST_Omron_B3F-50xx
Start1: SW_Omron_B3FS; SW_SPST_Omron_B3F-50xx
U1: ESP32_30pin
U2: LD1117S33TR_SOT223; SOT-223-3_TabPin2

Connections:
//AF_CIRCULO: J2.10, J4.3, U1.7 (GPIO26)
//AF_CRUZ: J2.9, J4.5, U1.8 (GPIO25)
//AF_CUADRADO: J2.5, J4.7, U1.4 (GPIO12)
//AF_L1: J2.7, J5.5, U1.6 (GPIO27)
//AF_L2: J2.11, J5.3, U1.10 (GPIO32)
//AF_MODE: J2.2, U1.18 (GPIO15)
//AF_R1: J2.8, J5.1, U1.9 (GPIO33)
//AF_R2: J2.4, J5.7, U1.3 (GPIO13)
//AF_TRIANGULO: J2.6, J4.1, U1.5 (GPIO14)
//AutoFire/AF_CIRCULO: J6.10, SW3.2 (B), SW3.5
//AutoFire/AF_CRUZ: J6.9, SW2.2 (B), SW2.5
//AutoFire/AF_CUADRADO: J6.5, SW6.2 (B), SW6.5
//AutoFire/AF_L1: J6.7, SW1.2 (B), SW1.5
//AutoFire/AF_L2: J6.11, SW4.2 (B), SW4.5
//AutoFire/AF_MODE: J6.2, SW9.2 (B)
//AutoFire/AF_R1: J6.8, SW5.2 (B), SW5.5
//AutoFire/AF_R2: J6.4, SW8.2 (B), SW8.5
//AutoFire/AF_TRIANGULO: J6.6, SW7.2 (B), SW7.5
//AutoFire/GND: D2.1 (K), J6.13, SW1.1 (A), SW2.1 (A), SW3.1 (A), SW4.1 (A), SW5.1 (A), SW6.1 (A), SW7.1 (A), SW8.1 (A), SW9.1 (A), SW10.3 (C)
//AutoFire/LED: D2.2 (A), R8.2
//GND: C1.2, C2.2, C3.2, C4.2, H2.1 (1_1), J1.4, J2.13, J3.2, J3.4, J3.6, J3.8, J4.2, J4.4, J4.6, J4.8, J5.2, J5.4, J5.6, J5.8, JP2.1 (A), JP3.1 (A), U1.2 (GND), U1.17 (GND), U2.1 (GND)
//JP3_ABAJO: J3.1, R4.2, U1.11 (GPIO35)
//JP3_ARRIBA: J3.7, R2.2, U1.14 (GPIO36)
//JP3_DERECHA: J3.5, R5.2, U1.13 (GPIO39)
//JP3_IZQUIERDA: J3.3, R3.2, U1.12 (GPIO34)
//PS1_ACK: J1.9, U1.22 (GPIO17)
//PS1_ATT: J1.6, U1.24 (GPIO18)
//PS1_CLK: J1.7, U1.23 (GPIO5)
//PS1_CMD: J1.2, U1.21 (GPIO16)
//PS1_DATA: J1.1, R1.2, U1.25 (GPIO19)
//SELECT: JP3.2 (B), Select1.3, Select1.4, U1.29 (GPIO22)
//START: JP2.2 (B), Start1.1 (1_1), Start1.4, U1.26 (GPIO21)
BATT_FROM_TP: C3.1, H1.1 (1_1), J2.12, J6.12, SW10.1 (A), U2.3 (VI)
PS1_PIN5: D1.2 (A), J1.5, JP1.1 (A), JP1.2 (B)
VCC_3V3: C1.1, C2.1, C4.1, D1.1 (K), D3.1 (K), D3.2 (A), J2.1, J6.1, R1.1, R2.1, R3.1, R4.1, R5.1, R8.1, SW10.2 (B), SW10.5, U1.16 (3.3v), U2.2 (VO)

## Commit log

2026-05-08 Initial ACT Labs PS1 Bluetooth project
    [ACT_Labs_Mapeo_Consolidado.xlsx, gpio_mapping.csv, jp1_conector_puente.csv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]
2026-06-24 V2 PCB checkpoint: LD1117, TP4056, D1, DATA ACK pullups
    [ACT_Labs_Consolidado_Final.xlsx, ACT_Labs_REX.kicad_pcb, ACT_Labs_REX.kicad_sch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]
2026-06-24 Update V2 documentation exports, BOM and fabrication files
    [ACT_Labs_REX_BOM.csv, AutoFire_BOM.csv, pos_ACT_Labs_REX.csv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]
2026-06-24 Remove duplicate position exports
    [pos_ACT_Labs_REX.csv, pos_AutoFire.csv]
2026-06-24 Remove legacy schematic PDF and keep V2 as official release
2026-06-24 docs: actualiza BOM V2
2026-06-24 docs: sincroniza README con hardware V2 y archivos de fabricacion
2026-06-24 docs: actualiza BOM desde exportaciones KiCad V2
2026-06-24 docs: amplía mapeo GPIO V2 para firmware
2026-06-24 docs: actualiza resumen de hardware y fabricacion
2026-06-24 docs: agrega guia de fabricacion V2
2026-06-24 docs: agrega registro de revision V2
2026-06-24 docs: agrega inventario de fuentes KiCad V2
2026-06-24 hardware: agrega resumen BOM placa principal V2
    [ACT_Labs_REX_BOM_summary.csv]
2026-06-24 hardware: agrega resumen POS placa principal V2
    [ACT_Labs_REX_POS_summary.csv]
2026-06-24 hardware: agrega resumen BOM AutoFire V2
2026-06-24 docs: ajusta referencias a archivos de fabricacion cargados
2026-06-24 docs: ajusta hardware README a resumenes de fabricacion
2026-06-24 docs: actualiza inventario de fuentes y hashes Rev 1.4
2026-06-26 docs: agrega arquitectura de interfaces
2026-06-26 docs: enlaza carpeta de interfaces en README
2026-06-26 docs: agrega referencia ESP32 pinout y notas GPIO
2026-06-27 chore: organiza fuentes KiCad y datos del proyecto
    [ACT_Labs_Consolidado_Final.xlsx, ACT_Labs_REX.kicad_pcb, ACT_Labs_REX.kicad_sch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]
2026-06-28 Add KrabenStick landing page
2026-06-28 Rebrand project as KrabenStick ESP32
2026-06-28 Use KrabenStick logo on landing page
2026-06-28 docs: elimina arquitectura de interfaces futuras
2026-06-28 docs: ajusta sitio a placa de repuesto ACT Labs REX
2026-06-28 docs: aclara que PS2 aun no esta implementado
2026-06-28 Add PayPal donation button
2026-06-28 Style PayPal donation button
2026-07-01 hardware: update ACT Labs REX KiCad sources and gerbers
    [ACT_Labs_REX-B_Cu.gbr, ACT_Labs_REX-B_Mask.gbr, ACT_Labs_REX-B_Paste.gbr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]
2026-07-01 docs: document clean KiCad and Gerber structure
2026-07-01 docs: update GitHub Pages landing page
2026-07-09 docs: mark KiCad update and gerbers pending
2026-07-09 docs: note gerbers pending after KiCad update
